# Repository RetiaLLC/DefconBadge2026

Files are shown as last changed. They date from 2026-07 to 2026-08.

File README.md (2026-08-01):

# DEF CON Badge (2026) — ESP32-S3

Everything you need to hack on the Retia DEF CON badge: hardware docs, pinouts, flashable firmware (including **DOOM**, a full **NES emulator**, **Meshtastic**, **MeshCore**, and **Reticulum**), and example code to get you from "just unboxed" to writing your own firmware.

> **🚀 Start here: the [Badge Launcher v2 "Touch"](https://github.com/RetiaLLC/badge-launcher/releases/tag/v2.0.0)** — the flagship badge experience. One flash + one micro-SD card turns the badge into a pick-what-you-run device: two full-color **touch mesh messengers** (MeshCore + Meshtastic MUI), classic Meshtastic, a **Reticulum RNode**, an **NES emulator** with a 37-game homebrew library, and **WLEDkitty** — switchable from an on-badge menu in ~10 seconds, no computer needed. Comes with a `MESH-101.md` that gets two badges messaging over LoRa in minutes. Flash it from your browser at [scriptkitty.sh](https://scriptkitty.sh). *(Requires a FAT micro-SD card — true of launcher v1 too. Prefer DOOM resident in flash? [Launcher v1 "Classic"](https://github.com/RetiaLLC/badge-launcher/releases/tag/v1.0.0).)*

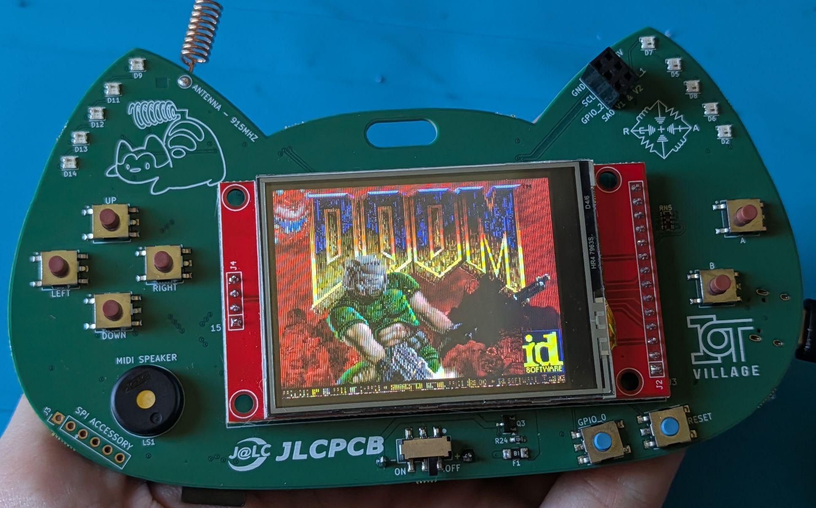
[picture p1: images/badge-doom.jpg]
The badge running DOOM


*Yes, that's DOOM. Flash it in one command — see below.*

## What's on the badge

| | |
|---|---|
| MCU | ESP32-S3-WROOM-1 — dual-core 240 MHz, WiFi + BLE, **8 MB flash**, **2 MB PSRAM**, native USB-C |
| Display | 2.4″ ILI9341 240×320 color TFT + XPT2046 resistive **touch** (MSP2402 module) |
| Radio | RFM95W **LoRa** 915 MHz (SX1276), U.FL antenna |
| Input | 6 face buttons (d-pad + A/B) + BOOT button usable as a 7th |
| Storage | micro-SD slot (tested to 16 GB SDHC) |
| Blinkies | 10× WS2812B NeoPixels, green debug LED |
| Sound | Piezo buzzer (MOSFET-driven) |
| Expansion | SAO v2, QWIIC (I²C), UART header, SPI header, off-board NeoPixel connector |
| Power | 2×AA (boost) or USB-C, auto-switching |

## Quick start: flash DOOM

```bash
pip install esptool
esptool --chip esp32s3 --port <PORT> write-flash 0x0 firmware/doom/doom-audio.factory.bin
```

`<PORT>` is `/dev/cu.usbmodem*` (macOS), `/dev/ttyACM0` (Linux), or `COMx` (Windows). Full instructions, port-finding, and un-bricking: [docs/flashing.md](docs/flashing.md).

## Repo map

```
docs/            pinout.md ← START HERE · hardware.md · flashing.md · sd-card.md
firmware/
  doom/          DOOM shareware, audio + silent builds (flash & play)
  meshtastic/    Meshtastic 2.7.23, standard + low-power builds
  reticulum/     RNode v1.85 — the badge as a Reticulum LoRa transceiver
examples/
  hello-badge/   buttons + LED + buzzer in 100 lines (your first build)
  sd-test/       mount/format/read/write the micro-SD slot
hardware/        KiCad 8 sources + schematic PDF
```

## The three things that bite everyone

1. **The touch controller and the display-module SD slot have crossed data lines** — hardware SPI can't reach them. The main SD slot and everything else work normally. Details: [docs/pinout.md](docs/pinout.md#hardware-quirks).
2. **Native-USB download-mode trap** — DTR-toggling serial monitors + reset = badge stuck "waiting for download". Fix: any esptool command ending in hard-reset. Details: [docs/flashing.md](docs/flashing.md#recovery).
3. **Never TX on LoRa without an antenna.** Receiving is safe; transmitting into nothing can cook the PA.

## Firmware in this repo

- **[DOOM](firmware/doom/)** — the 1993 classic, natively, full speed. D-pad moves, A fires, GPIO0 switches weapons. Audio build plays SFX through the piezo.
- **[Meshtastic](firmware/meshtastic/)** — off-grid LoRa mesh messaging with phone app support; standard, power-optimized, and full **color touch UI (MUI)** builds. **Ready-to-flash touch UI: [meshtastic-mui-v2.7.23 release](https://github.com/RetiaLLC/DefconBadge2026/releases/tag/meshtastic-mui-v2.7.23)** — on-screen keyboard, node map, touch region picker, phone TCP API alongside the home screen.
- **[MeshCore](firmware/meshcore/)** — the badge as a [MeshCore](https://meshcore.io) LoRa mesh node, hardware-verified badge-to-badge (messages + ACKs). The flagship build is a full **standalone touchscreen mesh communicator** — chats, contacts, channels, on-screen keyboard, RF monitor + spectrum analyzer, chimes, D-pad nav — that is simultaneously a BLE companion for the official MeshCore phone app. Plain companion (BLE/USB) builds too. **Ready-to-flash images: [meshcore-v1.0.0 release](https://github.com/RetiaLLC/DefconBadge2026/releases/tag/meshcore-v1.0.0).** Source: **[RetiaLLC/MeshCore](https://github.com/RetiaLLC/MeshCore)** (board variant) + **[RetiaLLC/wadamesh](https://github.com/RetiaLLC/wadamesh)** (touch messenger), both branch `retia-badge`.
- **[Reticulum / RNode](firmware/reticulum/)** — turns the badge into an [RNode](https://unsigned.io/rnode/): a host-controlled 915 MHz LoRa transceiver for the [Reticulum network stack](https://reticulum.network) (NomadNet, Sideband, MeshChat). The default build shows the live RNode status screen (frequency, airtime, channel load, signal) on the TFT. Flash, provision with `rnodeconf`, done — hardware-verified against a Nibble Zero RNode. Full toolkit, source, and Nibble Zero builds live in **[RetiaLLC/NibbleReticulum](https://github.com/RetiaLLC/NibbleReticulum)**.
- **[ESP32 Bus Pirate](firmware/buspirate/)** — a multi-protocol hardware-hacking multitool on the badge TFT (also USB-serial / Wi-Fi web CLI): I²C/SPI/UART/1-Wire/JTAG bus tools with **on-screen bus scan + live register monitor** and a **BME280 dashboard** that colours the ears by temperature, plus a full **on-screen LoRa/RF suite** — heat-map **waterfall**, packet **sniffer**, live **RSSI meter**, band **scanner**, and a **Meshtastic monitor** that decodes real mesh packets on-screen (with a **MeshCore** sniffer preset). Wi-Fi/BLE scanners too. **Start with the [beginner's guide](firmware/buspirate/GUIDE.md).** ⚠ Transmit- & attack-capable (Wi-Fi deauth, BLE spoof, RF jam) — **authorized use only**. Ready-to-flash: **[RetiaLLC/ESP32-Bus-Pirate @ badge-v1.2.1](https://github.com/RetiaLLC/ESP32-Bus-Pirate/releases/tag/badge-v1.2.1)**, ported from [KonradIT/geo-tp](https://github.com/KonradIT/ESP32-Bus-Pirate).
- **[Anemoia NES](https://github.com/RetiaLLC/Anemoia-DefconBadge)** *(standalone repo)* — a full NES emulator: put `.nes` ROMs on the micro-SD card, browse and launch them on the badge, and play with the D-pad + A/B. Save states, chiptune audio through the piezo, and a one-button START/SELECT scheme (tap BOOT = START, hold = pause menu). Ready-to-flash image on the [release page](https://github.com/RetiaLLC/Anemoia-DefconBadge/releases/latest) (also attached to this repo's `anemoia-v1.0.0` release), plus a [curated list of legally-free homebrew games](https://github.com/RetiaLLC/Anemoia-DefconBadge/blob/main/GAMES.md) tested on the badge. Ported from [Shim06/Anemoia-ESP32](https://github.com/Shim06/Anemoia-ESP32).

## Building your own firmware

Both examples are PlatformIO ESP-IDF projects with the badge board definition included — copy one as a template. The short version:

```bash
pip install platformio
cd examples/hello-badge
pio run -t upload --upload-port <PORT>
```

Then open a serial monitor at 115200 and press buttons.

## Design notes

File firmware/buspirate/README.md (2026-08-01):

# ESP32 Bus Pirate

A port of the open-source **[ESP32 Bus Pirate](https://github.com/KonradIT/ESP32-Bus-Pirate)** (geo-tp / KonradIT) to the badge — a multi-protocol hardware-hacking multitool driven from the badge TFT, USB-serial CLI, or a Wi-Fi web CLI.

Source & release: **[RetiaLLC/ESP32-Bus-Pirate @ badge-v1.2.1](https://github.com/RetiaLLC/ESP32-Bus-Pirate/releases/tag/badge-v1.2.1)** (branch `retia-badge-port`, all badge support gated behind `-DDEVICE_RETIA_BADGE`).

**New to it? Read the [beginner's guide](GUIDE.md)** — walks through every on-screen demo you can run on a bench.

## ⚠ Read before flashing — transmit- & attack-capable
Alongside the benign bus tools this firmware can **transmit and attack**: Wi-Fi (scan/sniff/**deauth**/nmap), Bluetooth LE (scan/**spoof**/sniff), LoRa/Sub-GHz **transmit**, and bus/RF **jam**. It ships as a full-capability image — not a passive build.

**Use only on hardware, networks, and RF you own or are authorized to test.** Transmitting against systems you don't own may be illegal. You are responsible for lawful use.

## What works on the badge (verified on hardware)
- **ILI9341 TFT UI** + **d-pad/A·B** nav; auto-boots to the USB-serial CLI.
- **LoRa on-screen suite** (on-board RFM95W / SX1276, new SX127x driver):
  - **`waterfall`** — heat-map spectrum analyzer (blue→red), peak-hold.
  - **`receive`** — packet sniffer: a rolling on-screen list (#, RSSI, length, ASCII).
  - **`rssi`** — big live signal meter + held-peak marker.
  - **`scan`** — peak-hold heat spectrum across a band.
  - **`mesh` → Receive** — Meshtastic monitor, decoded packets on-screen; verified vs a **real Meshtastic node**. `send` for TX.
  - **`meshcore`** — tunes to MeshCore's 915/SF10 PHY and sniffs (payloads AES-128, shown raw).
  - Core `send`/`receive`/`sniff`/`setfreq` **TX + RX verified badge-to-badge**.
- **I²C** — bus scan + live register **monitor on the TFT**; **`bme`** decodes a **BME280** (temp/humidity/pressure) on screen and colours the ear NeoPixels by temperature.
- **LED** — 10 ear NeoPixels (fill / rainbow / chase / wave).
- **Wi-Fi** and **BLE** scanners; **UART** sniff/autobaud.

## Wiring targets
I²C on the **SAO header (J5)**: 3V3 / GND / SDA=GPIO35 / SCL=GPIO36. UART on J4 (TX 43 / RX 44). ⚠ The badge's Qwiic connectors are pin-reversed vs. the standard — use **J5**, not Qwiic.

## Flash it
Browser (recommended, with the authorization prompt): **[catbadge.online](https://catbadge.online)** or **[scriptkitty.sh](https://scriptkitty.sh)**. Or with esptool:
```bash
esptool --chip esp32s3 --before default-reset --after hard-reset \
  write-flash --flash-mode dio --flash-freq 40m --flash-size 8MB 0x0 buspirate-badge.factory.bin
```

`buspirate-badge.factory.bin` — SHA-256 `695a924b2502d7e25b8057c3875d239c373009075f11e1cfee5f0772d6851cc6`

## Wi-Fi web CLI terminal
Boot into **WiFi Hotspot** or **WiFi Connect** and the badge serves an interactive web
terminal — type commands from any browser (phone included), no cable needed. The earlier
"Connection lost" flakiness is **fixed**: the badge now binds its reply socket from the
incoming WebSocket frame (the handshake binding didn't stick on this ESP-IDF), sends
complete (non-fragmented) frames, and reserves enough HTTP handlers for every route.
USB serial and browser Web Serial ([catbadge.online](https://catbadge.online)) remain
available for cabled use.

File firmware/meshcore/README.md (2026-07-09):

# MeshCore on the badge

Off-grid LoRa mesh messaging — [MeshCore](https://meshcore.io) v1.16.0 ported to the badge (SX1276 DIO0-only radio, ILI9341 + XPT2046 touch, all on the shared SPI bus). US 915 MHz preset by default; hardware-verified badge-to-badge with delivery ACKs.

**Flashable images live on the [`meshcore-v1.0.0` release](https://github.com/RetiaLLC/DefconBadge2026/releases/tag/meshcore-v1.0.0):**

| Image | What it is |
|---|---|
| `meshcore-touch-messenger.factory.bin` | **The one to use** — full standalone touchscreen mesh communicator (chats, contacts, channels, on-screen keyboard, RF monitor/spectrum apps, chimes, D-pad nav) that is *also* a BLE companion for the phone app |
| `meshcore-companion-ble.factory.bin` | Badge as a radio for the MeshCore phone app; pairing PIN shows on the badge screen |
| `meshcore-companion-usb.factory.bin` | Companion over USB serial for `meshcore-cli` / meshcore.js / the web client |

```bash
esptool --chip esp32s3 --port <PORT> write-flash 0x0 meshcore-touch-messenger.factory.bin
```

Source: [RetiaLLC/MeshCore](https://github.com/RetiaLLC/MeshCore/tree/retia-badge) (board variant) · [RetiaLLC/wadamesh](https://github.com/RetiaLLC/wadamesh/tree/retia-badge) (touch messenger). Repeater and room-server roles build from the same variant (`Retia_DCBadge_repeater` / `_room_server`).

**Badge-launcher note:** these are factory images with their own partition tables — they are **not** launcher SD-card guests. The touch messenger's app image (2.7 MB) exceeds the launcher's 2.375 MB shared slot, and MeshCore stores its identity/contacts in the same flash regions Meshtastic uses for settings, so running it as a guest would clobber them. Flash over USB instead (10 seconds), and hold UP at reset any time to get back to the launcher's factory image if you have it installed.

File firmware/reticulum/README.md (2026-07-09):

# Reticulum (RNode)

The badge as an [RNode](https://unsigned.io/rnode/): a host-controlled
[Reticulum](https://reticulum.network) LoRa transceiver. Plug it into a
computer or phone and use it with `rnsd`, NomadNet, MeshChat, or Sideband —
the badge handles the 915 MHz radio, the host runs the network stack.

Canonical repo (source, flash/provision scripts, Nibble Zero builds):
**[RetiaLLC/NibbleReticulum](https://github.com/RetiaLLC/NibbleReticulum)**

> ⚠️ **Attach a 915 MHz antenna (U.FL) before transmitting.** Transmitting
> without an antenna can damage the radio's PA. Receiving is safe.

## Flash it

```bash
pip install esptool rns
esptool --chip esp32s3 --port <PORT> write-flash 0x0 rnode-1.85-tft.factory.bin
```

Then provision the EEPROM (one time — makes it a valid homebrew RNode):

```bash
rnodeconf <PORT> -r --platform 80 --product f0 --model fe --hwrev 1
rnodeconf --info <PORT>   # should report: RNode v1.85, Normal (host-controlled)
```

Or let the automated script in NibbleReticulum do both:
`./DefconBadge/flash_dcbadge.sh <PORT>`.

| File | What |
|---|---|
| `rnode-1.85-tft.factory.bin` | **Recommended.** RNode v1.85 with the status screen on the badge's ILI9341 (mode, frequency, airtime, channel load, signal quality — 2.5x scale, full panel height). Flash at `0x0`. |
| `rnode-1.85.factory.bin` | Same firmware, headless (display dark). Flash at `0x0`. |

## Use it with Reticulum

Add to your `~/.reticulum/config` (LA-area community channel shown —
see the [NibbleReticulum SIGINT survey](https://github.com/RetiaLLC/NibbleReticulum/blob/main/SIGINT.md)):

```ini
[[RNode Badge]]
  type = RNodeInterface
  enabled = yes
  port = /dev/ttyACM0
  frequency = 914875000
  bandwidth = 125000
  spreadingfactor = 8
  codingrate = 5
  txpower = 17
```

Verified on hardware: bidirectional badge ↔ Nibble Zero Reticulum link,
3/3 packets delivered with proofs (914.875 MHz / SF8 / 125 kHz / CR5).

## Notes for builders

- Source: [`RetiaLLC/RNode_Firmware` branch `retia-stable`](https://github.com/RetiaLLC/RNode_Firmware/tree/retia-stable),
  targets `make firmware-retia_dcbadge_tft` (display) / `make firmware-retia_dcbadge` (headless, board ID `0x47`)
- `MODEM SX1276` only — the RFM95W's DIO1/BUSY are not routed
- The badge's SPI pins are **not** the ESP32-S3 defaults; the driver needs the
  explicit `SPI.begin(13, 12, 11, 48)` (already handled on the branch)
- Touch and SD chip-selects (14/39) are parked high at boot; the radio driver
  must never call `SPI.end()` on this board (shared display bus)
- Status: green debug LED (GPIO 2) blinks RX/TX; first NeoPixel = status color

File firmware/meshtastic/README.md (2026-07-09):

# Meshtastic

The badge is a fully working [Meshtastic](https://meshtastic.org) node: 915 MHz LoRa mesh, TFT UI, buttons, BLE to the phone app. Firmware 2.7.23 with a badge-specific variant (`hwModel PRIVATE_HW`).

> ⚠️ **Attach a 915 MHz antenna (U.FL) before joining a mesh.** Transmitting without an antenna can damage the radio's PA. And set your region before use:
> ```bash
> pip install meshtastic
> meshtastic --port <PORT> --set lora.region US
> ```

## Flash it

```bash
esptool --chip esp32s3 --port <PORT> write-flash 0x0 meshtastic-2.7.23-standard.factory.bin
```

| File | What |
|---|---|
| `meshtastic-2.7.23-standard.factory.bin` | Stock-behavior build for the badge variant (classic button-driven TFT UI). |
| `meshtastic-2.7.23-lowpower.factory.bin` | Power-tuned build: idle draw cut ~39% (NeoPixels off by default, BLE off until enabled by phone), B button = Back/Cancel, 40 ms debounce, battery light-sleep available as opt-in (`--set power.is_power_saving true` — battery-only deployments; USB presence inhibits sleep). |
| `meshtastic-2.7.23-mui-touch.factory.bin` | **Experimental color touch UI** (Meshtastic device-ui / LVGL, `touchscreen-build-bleoff`). Full touchscreen operation out of the box — on-screen keyboard, tap navigation — despite the badge's crossed touch data lines (worked around with a calibrated bit-banged XPT2046 driver). D-pad + A/B also work as a keypad. Bluetooth is off in this build (it conflicts with the touch UI's home screen); phone/client connectivity is WiFi/TCP (port 4403). Showcase build; the low-power build is the daily driver. |

A Meshtastic badge enumerates over USB with its MAC in the port name (e.g. `usbmodem744DBD216494`) — that's normal.

## Variant files

`variant.h` / `pins_arduino.h` in this directory are the badge variant used to build these images (RFM95W on the shared SPI bus, ILI9341 TFT, buttons as trackball input, NeoPixel ambient lighting). Drop them into `variants/esp32s3/` in the Meshtastic firmware tree to build your own.

Notes for builders:
- `USE_RF95` only — the radio's DIO1/BUSY are not routed, SX126x variants won't work
- USB serial console carries the protobuf client API, **not** a text log (human-readable log is on UART J4)
- The badge has no battery-voltage sense; don't enable battery-percentage features

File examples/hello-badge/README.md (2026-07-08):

# hello-badge

Your first badge program: heartbeat on the green LED, a beep and a console line for every button press (each button gets its own pitch — B is the loudest, it sits on the piezo's 4 kHz resonance).

```bash
pio run -t upload --upload-port <PORT>
pio device monitor -p <PORT> -b 115200
```

Press buttons. That's it. Copy this project as the starting point for your own firmware — the board definition in `boards/` already knows the badge's flash/PSRAM setup.

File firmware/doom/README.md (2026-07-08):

# DOOM

Yes, really. PrBoom 2.5.0 running the shareware **DOOM** (Knee-Deep in the Dead) natively on the badge — 320×240 fullscreen, all game logic, attract demos, saves-free arcade style. The WAD is memory-mapped straight out of flash so the whole game fits in the S3's 2 MB PSRAM.

## Flash it

```bash
esptool --chip esp32s3 --port <PORT> write-flash 0x0 doom-audio.factory.bin
```

| File | Sound |
|---|---|
| `doom-audio.factory.bin` | Sound effects through the piezo buzzer (loud-ish, crunchy, gloriously PC-speaker). Three self-test chirps at boot. |
| `doom-silent.factory.bin` | Mute. Same game otherwise. |

Music is not implemented in either build (there's no MIDI synth in this port — yet).

## Controls

| Input | Action |
|---|---|
| D-pad | Move forward/back, turn left/right |
| **A** (SW8) | Fire — also Enter in menus |
| **B** (SW7) | Use / open doors — Space in menus |
| **A+B together** | Escape (open/close menu) |
| **BOOT** (SW2, top of badge) | Switch weapon (best-available toggle) |

At the title screen: **A+B** → menu → **A** to start New Game.

## How it works / source

Port derived from [cocus/esp32-ili9341-doom-lvgl](https://github.com/cocus/esp32-ili9341-doom-lvgl) (itself from [espressif/esp32-doom](https://github.com/espressif/esp32-doom)), retargeted to the badge:

- Badge pin map, all six face buttons + BOOT wired to Doom keys
- IWAD (`doom1.wad`, shareware — freely redistributable) and PrBoom's data WAD live in dedicated flash partitions, memory-mapped, lumps read in place
- Zone allocator backed by PSRAM with cache eviction — fits the 2 MB
- 8-bit palette renderer → RGB565 over 40 MHz SPI
- Audio build: 1-bit sigma-delta on the buzzer GPIO, 22 kHz sample timer, heavy gain+clip (a piezo demands it)

Flash layout inside the factory image: bootloader `0x0`, partition table `0x8000`, app `0x10000`, `doom1.wad` `0x210000`, `prboom-plus.wad` `0x630000`.

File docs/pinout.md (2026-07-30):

# GPIO Pinout — 2024 DEF CON Badge (ESP32-S3)

MCU: **ESP32-S3-WROOM-1** module — dual-core LX7 @ 240 MHz, **8 MB flash** (GigaDevice, QIO-capable), **2 MB embedded PSRAM** (quad, 80 MHz), native USB.

> ⚠️ Read the [quirks](#hardware-quirks) section before writing firmware. Several pins are shared, one pair is crossed in hardware, and the native-USB download mode has a trap.

## Complete GPIO map

| GPIO | Function | Direction | Notes |
|-----:|---|---|---|
| 0 | **BOOT button (SW2**, silkscreen "GPIO_0"**)** + off-board NeoPixel connector J8 (level-shifted to 5 V) | in / out | Strap pin: hold low through a reset → ROM download mode. Free as a button input after boot. |
| 1 | SAO connector GPIO1 (J5 pin 5) | any | |
| 2 | **Green debug LED** (330 Ω) + SAO GPIO2 (J5 pin 6) | out | |
| 3 | **LEFT button (SW3)** | in | Active-low, external 10 kΩ pull-up. Debounce caps C7–C12 are DNP (not populated). |
| 4 | **UP button (SW4)** | in | Active-low, 10 kΩ pull-up |
| 5 | **DOWN button (SW5)** | in | Active-low, 10 kΩ pull-up |
| 6 | **RIGHT button (SW6)** | in | Active-low, 10 kΩ pull-up |
| 7 | **B button (SW7)** | in | Active-low, 10 kΩ pull-up |
| 8 | **A button (SW8)** | in | Active-low, 10 kΩ pull-up |
| 9 | **Buzzer** (silkscreen "MIDI SPEAKER"; 330 Ω → NMOS gate → PS1240P02CT3 piezo from +5 V, 1 kΩ parallel) | out | Square wave ≈4 kHz is loudest (piezo resonance). 1-bit sigma-delta works for sampled audio (quiet, crunchy). |
| 10 | **micro-SD card CS** (dedicated slot, 10 kΩ pull-up) | out | Shares the SPI bus. Verified working — see [sd-card.md](sd-card.md). |
| 11 | **SPI MOSI** (shared bus) | out | Also: touch T_DO and module-SD "SD_MISO" land here — see quirks. |
| 12 | **SPI MISO** (shared bus) | in | Also: touch T_DIN and module-SD "SD_MOSI" land here — see quirks. |
| 13 | **SPI SCK** (shared bus) | out | Display runs at 40 MHz; SD at 20 MHz; touch ≤2.5 MHz. |
| 14 | **Touch controller CS** (XPT2046 on display module) | out | |
| 15 | 32.768 kHz crystal (XTAL_32K_P) | — | Not available as GPIO |
| 16 | 32.768 kHz crystal (XTAL_32K_N) | — | Not available as GPIO |
| 17 | **On-board NeoPixels** — 10× WS2812B-2020, right ear (5) then left ear (5) | out | |
| 18 | Broken out to MCU_gpio bus, unused on the board | any | |
| 19 | USB D− | — | |
| 20 | USB D+ | — | |
| 21 | **LoRa DIO0 / IRQ** (RFM95W) | in | |
| 35 | **I²C SDA** — SAO (J5) and QWIIC (J6) | any | Chosen for software compatibility with HakCat Nuggets (no dedicated I²C pins). |
| 36 | **I²C SCL** — SAO (J5) and QWIIC (J6) | any | |
| 37 | **Accessory SPI CS** (J3, unpopulated header) | out | |
| 38 | **LoRa RESET** (RFM95W, 10 kΩ pull-up) | out | |
| 39 | **Display-module SD slot CS** | out | ⚠️ That slot's data lines are crossed — see quirks. |
| 40 | **TFT DC** (data/command) | out | |
| 41 | **TFT RESET** | out | |
| 42 | **Touch IRQ** (XPT2046 PENIRQ, active low) | in | |
| 43 | **UART TX** (J4 accessory header, 330 Ω series) | out | Default ESP-IDF console is here unless retargeted to USB. |
| 44 | **UART RX** (J4) | in | |
| 45 | Unconnected | — | Strap pin (VDD_SPI voltage) — leave alone |
| 46 | Unconnected | — | Strap pin — leave alone |
| 47 | **TFT CS** (ILI9341) | out | |
| 48 | **LoRa CS** (RFM95W, 10 kΩ pull-up) | out | |

## The shared SPI bus

One SPI bus (SCK 13 / MOSI 11 / MISO 12) serves **five** peripherals, each with its own chip-select:

| Device | CS | Max clock |
|---|---|---|
| ILI9341 TFT (240×320) | 47 | 40 MHz (overclocked, works) |
| RFM95W LoRa | 48 | 10 MHz |
| micro-SD slot (dedicated) | 10 | 20 MHz |
| SD slot on display module | 39 | — (crossed lines, unusable as-is) |
| XPT2046 touch | 14 | 2.5 MHz (crossed lines — bit-bang only) |
| Accessory header J3 | 37 | — |

**Rule: before using any bus device, drive every other CS high.** A floating CS (especially the LoRa radio's) will corrupt bus traffic.

## Hardware quirks

1. **Touch data lines are crossed.** The XPT2046's T_DIN (its input) is wired to GPIO12 — the bus **MISO** net — and T_DO (its output) to GPIO11, the bus **MOSI** net. Hardware SPI can therefore never talk to the touch controller. It *is* reachable by bit-banging with reversed pin roles (drive commands on 12, read data on 11) while holding the bus. T_IRQ (GPIO42, active low on touch) works normally.
2. **The display module's own SD slot has the same crossing** ("SD_MISO"→GPIO11/MOSI, "SD_MOSI"→GPIO12/MISO). Use the **dedicated** micro-SD slot (CS 10) instead — it's wired correctly and verified working.
3. **Native-USB download-mode trap.** The USB-Serial/JTAG peripheral wires host DTR to GPIO0. A serial monitor that asserts DTR, combined with a reset, drops the badge into ROM download mode ("waiting for download") instead of booting. Flash with esptool `--after hard-reset`, avoid DTR-toggling monitors, and see [flashing.md](flashing.md#recovery) for recovery.
4. **Display backlight is hardwired to 3.3 V** — always on, not software-controllable (~0.2–0.35 W). A white screen just means the panel is in sleep with the backlight lit.
5. **No battery voltage sense.** GPIO45/46 are unconnected; +BATT and +USB_IN are power-only. Firmware cannot read battery level — USB presence is the only "external power" signal (USB plugged in ⇒ battery path disabled).
6. **LoRa DIO1/BUSY are not routed.** Use SX127x/RF95 drivers only (`USE_RF95`, `LORA_DIO1 = NC`); SX126x variants will not work.
7. **8 MB flash despite what USB says.** Chip identification may report "FH4R2 (4 MB)" but the module carries an 8 MB GigaDevice part (`flash-id`: c8:4017). Partition freely up to 8 MB.
8. **Merged-image builders: use DIO flash mode.** A factory image with a QIO bootloader header boot-loops at ROM stage (`TG0WDT` reset + `ets_loader.c 78`). The second-stage bootloader enables QIO itself; the header must stay DIO.
9. **⚠️ Qwiic/STEMMA-QT connectors (J4, J6) are pin-reversed vs. the standard — do NOT plug in stock Qwiic sensors.** The JST-SH footprint is mounted so the physical pin order is **backwards** relative to the SparkFun-Qwiic / Adafruit-STEMMA-QT cable standard, so a standard cable lands **power and ground swapped/scrambled** — the sensor never powers up and a small host (e.g. a Nugget) can brown out and fail to boot. Affects both I²C (J6) and the UART-on-Qwiic (J4), and the same footprint is shared across other Retia boards. **Workaround:** wire I²C to the **SAO header (J5)** instead — pin 1 = +3.3 V, 2 = GND, 3 = SDA/GPIO35, 4 = SCL/GPIO36 — after metering. Full analysis + fix in [hardware-errata.md](hardware-errata.md).

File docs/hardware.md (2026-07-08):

# Hardware Guide — 2024 DEF CON Badge

A sheet-by-sheet walkthrough of the design ([schematic.pdf](../hardware/schematic.pdf), KiCad 8 sources in [hardware/kicad](../hardware/kicad/)).

## System overview

```
2×AA ──SW9──F1──► TPS61023 boost (5.1V) ─┐
                                          ├─► +5V rail ──► TLV62569 buck ──► +3.3V rail
USB-C VBUS ──────────► diode D10 ────────┘
```

- **ESP32-S3-WROOM-1** module (8 MB flash, 2 MB PSRAM)
- **MSP2402** 2.4″ display module: ILI9341 240×320 TFT + XPT2046 resistive touch + micro-SD slot
- **RFM95W** 915 MHz LoRa radio (SX1276) with U.FL antenna connector
- 10× **WS2812B-2020** NeoPixels (two "ears" of 5)
- Piezo buzzer, 6 face buttons + BOOT/RESET, dedicated micro-SD slot
- SAO v2, QWIIC, UART, SPI accessory headers, off-board NeoPixel connector

## Power (sheet 7)

Two power sources, diode-OR'd onto the +5 V rail:

- **Battery path:** 2×AA → power switch SW9 → polyfuse F1 → **TPS61023** boost converter set to **5.1 V** (R27 750k / R28 100k). The extra 0.1 V biases D10's drop so USB wins when both are present.
- **USB path:** VBUS → diode D10 → +5 V rail. A MOSFET (Q4) **disables the boost converter whenever USB is present** — so battery current is zero on USB power, and firmware can treat "USB plugged in" as "not on battery".
- **3.3 V:** TLV62569 buck (R30 453k / R31 100k → 3.318 V) feeds the MCU, radio, display logic.
- Reverse-battery indicator: red/green LED pair across the input.

Consequences for firmware: no brownout mystery — a badge that resets under load on AA power is hitting the boost converter's current limit (NeoPixels + radio TX + display are a real load). The display backlight is a constant ~0.2–0.35 W drain you cannot switch off.

## MCU block (sheet 2)

- SW1 = RESET (EN), SW2 = BOOT (GPIO0) — the standard ESP32 programming pair.
- Green debug LED on GPIO2 (also on the SAO header).
- 32.768 kHz crystal on GPIO15/16 for RTC deep-sleep timing.
- Full pin map: see [pinout.md](pinout.md).

## Display + touch + module SD (sheet 4)

The MSP2402 module carries three devices; the badge fans all of them onto the shared SPI bus through DR-series resistor networks:

- **TFT (ILI9341):** CS 47, DC 40, RST 41 — wired correctly, runs happily at 40 MHz. Backlight pin is tied to 3.3 V (always on).
- **Touch (XPT2046):** CS 14, IRQ 42, clock shared — but **T_DIN/T_DO are swapped** relative to the bus (T_DO→MOSI net, T_DIN→MISO net). Hardware SPI cannot reach it; reversed-role bit-banging can. IRQ works and is the cheap "is anyone touching" signal.
- **Module SD slot:** CS 39 — **same MISO/MOSI swap**, so leave it alone and use the dedicated slot below.

## Dedicated micro-SD (sheet 5)

Correctly wired SPI slot: CS **10** (10 kΩ pull-up), plus the shared bus pins. Verified working at 20 MHz with a 16 GB SDHC card — see [sd-card.md](sd-card.md) and [examples/sd-test](../examples/sd-test/).

## Buttons (sheet 8)

Six face buttons — LEFT 3, UP 4, DOWN 5, RIGHT 6, B 7, A 8 — all to ground with 10 kΩ pull-ups. Footprints for RC debounce caps (C7–C12) exist but are **not populated**; debounce in software (~40 ms works well).

## Buzzer (sheet 3)

GPIO9 → 330 Ω → NMOS gate (10 kΩ pull-down) → **PS1240P02CT3 piezo** from +5 V with 1 kΩ parallel damping resistor. It's a resonant tweeter, loudest around 4 kHz:

- Simple beeps: LEDC PWM square wave, 2–5 kHz. Loud and clean.
- Sampled audio: 1-bit sigma-delta (or LEDC-PWM DAC) works, but off-resonance output is quiet and gritty. Apply heavy gain + clipping. (The Doom build does exactly this.)

## LoRa radio (sheet 9)

**RFM95W-915S2** (SX1276): CS 48, RESET 38, DIO0/IRQ 21, shared SPI. DIO1+ are **not connected** — SX127x-style drivers only. Antenna via U.FL (J1) or the TP1 wire pad.

> ⚠️ **Never transmit without a 915 MHz antenna attached** — you can damage the PA. Receiving is safe.

## NeoPixels (sheets 10, 6)

- On-board: GPIO17 → 10× WS2812B-2020, right ear first (D2,D6,D8,D5,D7), then left (D9,D11,D12,D13,D14). Powered from 3.3 V (works fine for WS2812B at 3.3 V logic).
- Off-board connector J8: **GPIO0** through a proper MOSFET level shifter (Q2) to 5 V logic, with 5 V supply on the header. Note the GPIO0 double-duty: driving external pixels means the pin also feels button SW2 and the boot strap — keep it high-Z at reset.

## Connectors (sheet 6)

| Ref | What | Pins |
|---|---|---|
| J3 | SPI accessory (unpopulated) | MISO 12, MOSI 11, SCK 13, CS 37, 3.3 V, GND |
| J4 | UART | TX 43, RX 44 (330 Ω series), 3.3 V, GND |
| J5 | **SAO v2** | SDA 35, SCL 36, GPIO1, GPIO2, 3.3 V, GND |
| J6 | **QWIIC** | SDA 35, SCL 36, 3.3 V, GND |
| J7 | USB-C | D− 19, D+ 20, CC pulldowns populated |
| J8 | NeoPixel out | GPIO0 (5 V level-shifted), 5 V, GND |
| J9 | 2×AA battery | via SW9 + polyfuse |

I²C on GPIO35/36 was picked deliberately for software compatibility with existing HakCat Nugget projects.

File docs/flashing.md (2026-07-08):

# Flashing Guide

Everything here uses the badge's **USB-C port** — no programmer needed. The ESP32-S3's native USB shows up as a serial port when you plug it in.

## 1. Install esptool

```bash
pip install esptool
```

## 2. Find the port

| OS | Port looks like |
|---|---|
| macOS | `/dev/cu.usbmodem*` |
| Linux | `/dev/ttyACM0` |
| Windows | `COM5` (check Device Manager) |

> A badge running Meshtastic enumerates with its MAC address in the port name (e.g. `usbmodem744DBD216494`); a badge in the ROM bootloader or running most other firmware shows a generic name.

## 3. Flash a factory image

Every `.factory.bin` in this repo is a **complete merged image** (bootloader + partition table + app + data). One command, always at offset 0:

```bash
esptool --chip esp32s3 --port /dev/cu.usbmodem1101 write-flash 0x0 doom-audio.factory.bin
```

The badge resets and boots the new firmware when the write finishes. If esptool can't connect, see manual download mode below.

## Manual download mode

Hold **BOOT (SW2)**, tap **RESET (SW1)**, release BOOT. The badge is now in the ROM serial bootloader waiting for esptool.

## Recovery

### Badge is stuck "waiting for download" after flashing

The S3's native USB wires the host's **DTR line toward GPIO0**, so serial monitors that assert DTR can hold the badge in download mode across resets. Fixes:

- Run any esptool command ending in a reset, e.g. `esptool --chip esp32s3 --port PORT flash-id` — it exits via "Hard resetting via RTS pin..." which boots the app.
- Close any open serial monitor before flashing or resetting (one client per port!).
- When scripting your own serial reader: hold DTR **steadily** asserted and never toggle it; toggling is what re-traps the chip.

### Badge boot-loops with `rst:0x7 (TG0WDT_SYS_RST)` and `ets_loader.c 78`

The flash image's bootloader header says QIO, which the ROM loader can't use on this flash chip (the second-stage bootloader is what switches to QIO). Reflash a known-good image, or if you're building merged images yourself: **`esptool merge-bin --flash-mode dio`**, never `qio`.

### Nuclear option

```bash
esptool --chip esp32s3 --port PORT erase-flash   # ~8 s, wipes everything incl. saved settings
```
Then flash a factory image.

## Reading the serial console

Firmware in this repo routes its console to the USB port. Any terminal at 115200 baud works, **but** prefer one that doesn't toggle DTR on open (see trap above). `pio device monitor` and most IDE monitors are fine while the app is running — just close them before flashing.

## Building from source

The examples are PlatformIO projects:

```bash
pip install platformio
cd examples/sd-test
pio run                                    # build
pio run -t upload --upload-port PORT       # flash
```

The board definition ([examples/sd-test/boards/defcon-badge.json](../examples/sd-test/boards/defcon-badge.json)) encodes the badge: ESP32-S3, 8 MB flash (QIO), 2 MB quad PSRAM.

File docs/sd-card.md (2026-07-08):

# Using the micro-SD Card

The badge has **two** SD interfaces. Only one of them works — know which.

## The two slots

| Slot | CS | Status |
|---|---|---|
| **Dedicated micro-SD slot** on the badge PCB | GPIO **10** | ✅ Works — use this one |
| Slot on the back of the display module | GPIO 39 | ❌ Data lines crossed in routing (MISO/MOSI swapped) — unusable with hardware SPI |

Both share the badge SPI bus (SCK 13 / MOSI 11 / MISO 12) with the display, touch, LoRa radio and accessory port. **Park every other chip-select high** (GPIOs 47, 48, 39, 37, 14) before touching the card, or bus traffic will collide.

## Verified configuration

Tested on real hardware with a 16 GB SDHC card ("SS16G"):

```
Name: SS16G
Type: SDHC
Speed: 20.00 MHz (limit: 20.00 MHz)
Size: 15193MB
sd-test: Wrote /sd/badge_test.txt
sd-test: Read back: Hello from the 2024 DEF CON badge!
sd-test: SD TEST: PASS (15193MB card, wrote and read /sd/badge_test.txt)
```

- Bus: SDSPI on `SPI2_HOST`, CS 10, 20 MHz (the ESP-IDF SDSPI default)
- Filesystem: FAT (FAT32 for cards ≥ ~2 GB). A FAT-formatted card mounts as-is.
- Cards that arrive exFAT (common ≥64 GB) or unformatted need a FAT format first — the example does it on the badge via `format_if_mount_failed = true` (**erases the card**), or format it FAT32 on your computer.

## Try it

[examples/sd-test](../examples/sd-test/) is a complete PlatformIO project that mounts the card (formatting if needed), prints the card info, writes `/sd/badge_test.txt`, reads it back, and blinks the green LED slow for PASS / fast for FAIL. Console output on USB at 115200.

```bash
cd examples/sd-test
pio run -t upload --upload-port <PORT>
```

## Minimal code

```c
spi_bus_config_t bus = { .mosi_io_num = 11, .miso_io_num = 12,
                         .sclk_io_num = 13, .quadwp_io_num = -1, .quadhd_io_num = -1 };
spi_bus_initialize(SPI2_HOST, &bus, SDSPI_DEFAULT_DMA);

sdmmc_host_t host = SDSPI_HOST_DEFAULT();
host.slot = SPI2_HOST;
sdspi_device_config_t slot = SDSPI_DEVICE_CONFIG_DEFAULT();
slot.gpio_cs = 10;
slot.host_id = SPI2_HOST;

esp_vfs_fat_sdmmc_mount_config_t cfg = { .format_if_mount_failed = true,
                                         .max_files = 5, .allocation_unit_size = 16*1024 };
sdmmc_card_t *card;
esp_vfs_fat_sdspi_mount("/sd", &host, &slot, &cfg, &card);
// ... standard stdio on /sd/... from here
```

Sharing the bus with a live display (as Doom does) additionally requires serializing access — take a lock around SD transactions so they interleave between display DMA frames.

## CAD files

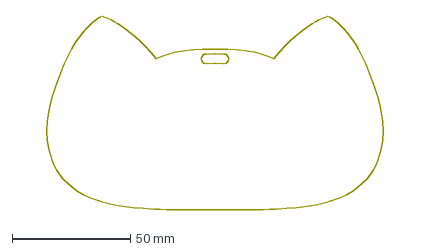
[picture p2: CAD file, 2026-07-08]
hardware/kicad/outlines/smoothbadge.dxf
168.2 x 82.8 mm

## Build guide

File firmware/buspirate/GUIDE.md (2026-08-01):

# ESP32 Bus Pirate on the DEF CON Badge — Beginner's Guide

> Turn your badge into a **multi-protocol hardware & radio analysis multitool** with
> a live color display. This guide gets you from "just flashed" to running eye-catching,
> hands-on demos — **no laptop screen required, the badge shows you everything.**
>
> Every command and on-screen result below was tested on the actual badge on a bench.

## Jump to

- [Quick start](#quick-start) — flash, connect, the CLI basics
- [LoRa demos](#lora-demos-the-stars) ⭐ — waterfall, sniffer, RSSI meter, scanner, Meshtastic/MeshCore
- [I²C sensor dashboard](#i2c-sensor-dashboard) — scan + decode a sensor on screen
- [GPIO pin tools](#gpio-pin-tools) — "is this pin alive?" + on-screen logic/analog scope
- [Wi-Fi](#wi-fi) — scan, MAC lookup, and driving the badge wirelessly
- [Bluetooth LE](#bluetooth-le) — scan the air
- [UART](#uart) — sniff a live serial line
- [LED ears](#led-ears) — because it's a badge
- [Needs an add-on module](#needs-an-add-on-module) — what's *not* on the badge
- [Command reference](#command-reference)

> ⚠️ **Radio safety & authorization.** This build can transmit (LoRa/Wi-Fi/BLE) and
> includes attack-capable commands (deauth, spoof, jam, spam). **Only test hardware,
> networks and RF you own or have written permission to test.** This guide sticks to
> **passive, receive-only demos** — the safe, always-legal stuff. Never transmit on
> LoRa without a 915 MHz antenna attached, or you can damage the radio.

---

## Quick start

1. **Flash** the badge — browser flasher at [catbadge.online](https://catbadge.online), or `esptool … write-flash 0x0 buspirate-badge.factory.bin`.
2. **Tap RESET.** It boots straight to the USB-serial CLI at **115200 baud**.
3. Useful anywhere:
   - `help` — commands for the current mode · `man` — built-in topic guide (examples, syntax, safety)
   - `mode` — list protocols · `mode <name>` — enter one (prompt changes: `I2C>`, `LORA>`, …)
   - `system` — opens a status shell (summary, memory, network, partitions, reboot…); pick `1` for the summary
   - `mode hiz` — safe idle · **ENTER** — stop a running command

> 💡 **Entering a mode asks a few setup questions** (pins, speed, radio settings), each
> showing its default in brackets like `SDA GPIO [35]:` — **just press ENTER to accept
> every default.** All examples below assume you took the defaults.

You can also drive the whole CLI **from a browser** (no terminal app) or **over Wi-Fi** —
see [Drive it wirelessly](#wi-fi).

### Where things are

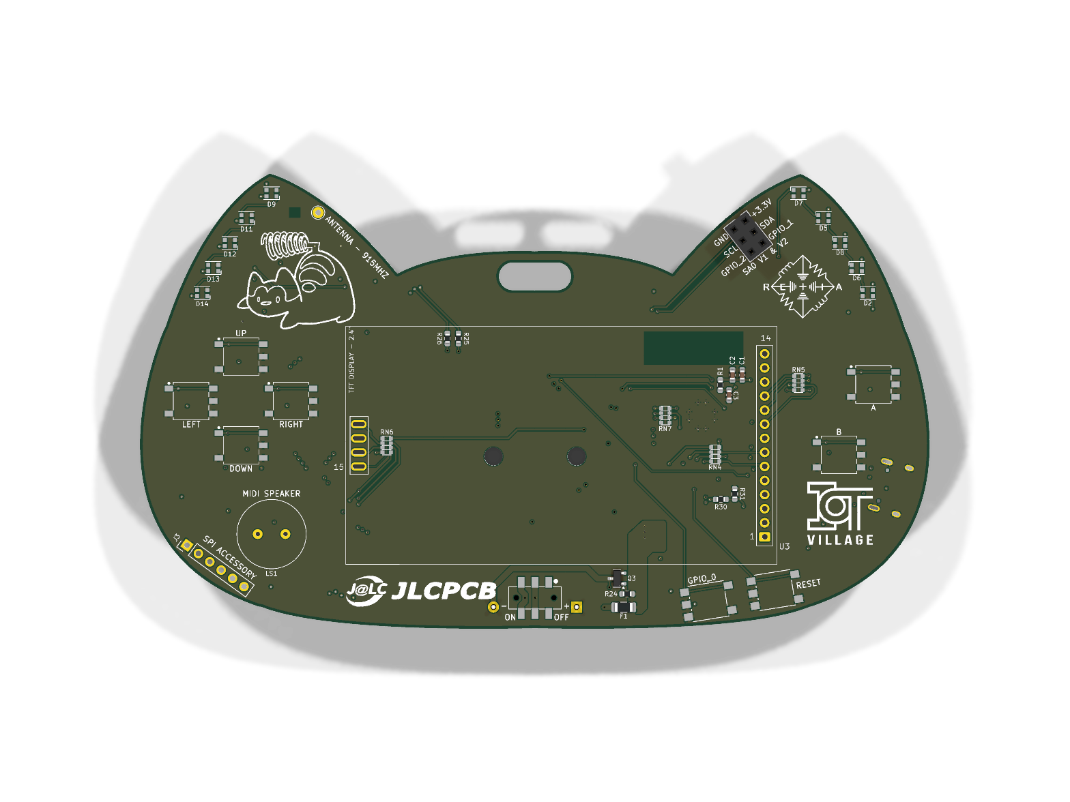
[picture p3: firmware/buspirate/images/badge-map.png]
Badge map — SAO port, d-pad + A/B/RESET buttons, 915 MHz antenna, SPI accessory header


The bits this guide uses: the **SAO port** (top-right, labelled `+3.3V / SDA / SCL /
GPIO_1 / GPIO_2 / GND`) for I²C add-ons; the **d-pad + A** for the boot menu; **A / B /
RESET** buttons; the **915 MHz antenna** pad for LoRa; and the **SPI accessory** header.
The **Qwiic (J6)** I²C connector is on the back.

---

## LoRa demos (the stars) ⭐

LoRa is where the on-screen demos shine.
```
mode lora
```
It reports the on-board radio (`RFM95W / SX127x`) and asks *"Configure radio settings?"* —
answer **N** for the sensible defaults. You're at `LORA>`.

> Attach the **915 MHz antenna** before anything that transmits (`send`, `spam`). The
> receive/scan demos are safe without one, but signals will be weak.

| Command | What the screen does |
|---|---|
| `waterfall` | **Heat-map spectrum analyzer** — blue/green where quiet, **yellow/red where something transmits**; peak frequency in the header. Try Start `902` End `928` Step `0.1`. |
| `rssi` | **Big live signal meter** + colored bar + held-peak marker. Move a transmitter closer, the bar climbs and turns red. |
| `scan` | **Peak-hold heat spectrum** across a range — every channel that's been active lights up and stays lit. |
| `receive` | **Packet sniffer** — a rolling on-screen list of frames: number, **RSSI**, length, ASCII preview. Have another badge `send hello world`. |
| `send <text>` | Transmit a frame (needs the antenna). Two badges: one `receive`, the other `send`. |

**Meshtastic monitor** — the badge decodes *real* Meshtastic:
```
mesh
```
From the numbered menu: **2** → preset `LongFast`, **3** → frequency `906.875`, **4** →
channel key `AQ==`, **7** → **Receive packets**. The screen becomes a **Mesh Monitor**
showing decoded packets — `!nodeid` + text/type — for any Meshtastic traffic on the
default channel. (Verified decoding live packets from a stock Meshtastic node.) Menu
**6** sends a text a real Meshtastic node/phone will receive.

**MeshCore sniffer** — one command:
```
meshcore
```
Tunes the radio to MeshCore's default US PHY (`915 MHz / SF10`) and drops into the
on-screen sniffer. MeshCore frames appear as RSSI + raw bytes (group payloads are
AES-128 encrypted, so they show raw, not decoded). It's a *separate* mode from
Meshtastic — different frequency/spreading-factor, can't monitor both at once.

---

## I²C sensor dashboard

The best hands-on demo if you have a sensor. Wire it to the badge's **Qwiic connector
`J6`** (the white JST) — match the sensor's **3V3 · GND · SDA · SCL** to the badge:

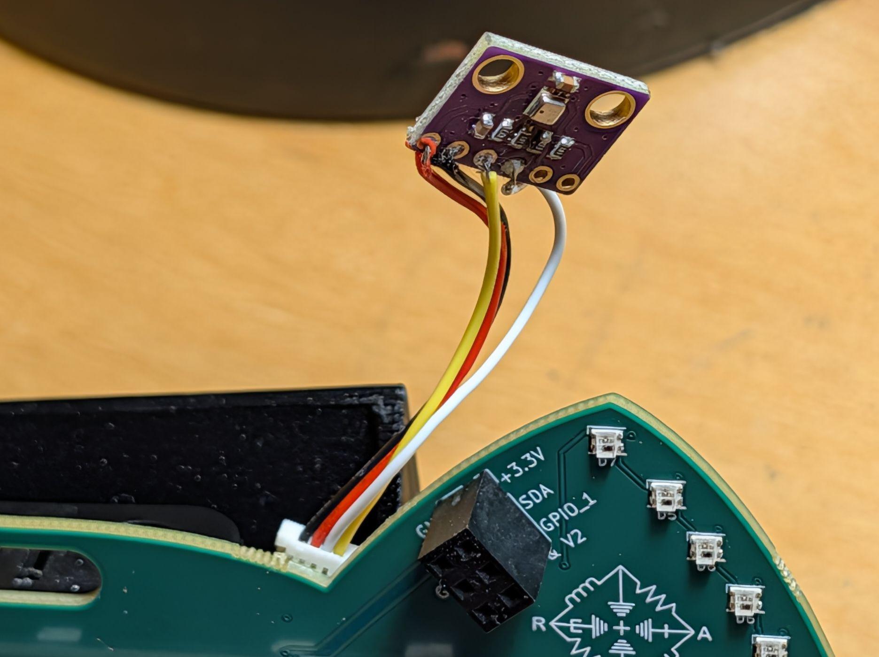
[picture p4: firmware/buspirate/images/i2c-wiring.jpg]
Wiring a BME280 I²C sensor into the badge's J6 Qwiic connector


> ⚠️ **`J6` (Qwiic) is pin-reversed vs a standard Qwiic/STEMMA cable** (see
> [`docs/hardware-errata.md`](../../docs/hardware-errata.md)) — a plug-and-play cable
> lands power/ground scrambled. **Hand-wire the four lines to match** the badge's
> silkscreen (`+3.3V / SDA / SCL / GND`), exactly like the photo above. Either I²C
> connector works — **`J5` (the SAO port)** carries the same bus (see below).

The badge's whole I²C bus is **SDA = GPIO35, SCL = GPIO36** — those are the default
`mode i2c` pins, and they're wired to *both* `J6` (Qwiic) and `J5` (the SAO port).

```
mode i2c
```
Answer `SDA GPIO [35]:`, `SCL GPIO [36]:`, `Frequency [100000]:` — **ENTER three times**.
Then:
```
scan
```
The screen shows a **device list**; serial prints `Found device at 0x76`. A BME280/BMP280
environment sensor answers at `0x76` (or `0x77`).
```
bme 0x76
```
Decodes the sensor **onto the badge**: a two-column **BME280** dashboard with **T / H / P**
(e.g. `T 24.9 C · H 49 %RH · P 1001 hPa`) plus raw registers — and **the ear LEDs change
color with the temperature.** Warm the sensor with your fingers and watch both move.
`monitor <addr>` mirrors live register reads to the screen. ENTER stops.

---

## Talk to an SAO on the SAO port

The **SAO port (`J5`)** — the standard 1×6 add-on header — is wired straight to the same
I²C bus (**SDA GPIO35 · SCL GPIO36**) plus two GPIOs (**GPIO1, GPIO2**, on pins 5 & 6).
So you can interrogate anything plugged into it with **no extra wiring**:

- **I²C parts on the SAO** (sensors, EEPROMs, LED drivers): `mode i2c` → `scan` finds the
  address, then `read` / `dump` / `bme` / `monitor` — same as the sensor dashboard above.
- **The SAO's two GPIO lines** (GPIO1, GPIO2): scope them on the badge screen with
  `logic 1` / `logic 2` (digital waveform) or `analogic 1` (live voltage), or poke them in
  `mode dio` (`read 1`, `measure 1`).

Great for reverse-engineering a mystery SAO: **scan its I²C address, then scope its GPIO
pins** — all from the badge, no laptop.

---

## GPIO pin tools

"Is this pin alive?" — and two commands that draw a **scope trace on the badge screen**.
These work from any prompt (they're global).

> **Use a broken-out GPIO**, not a reserved one. Safe to probe on this badge:
> **1, 2, 18, 35, 36, 37** (SAO/accessory header) and **43, 44** (UART header). The
> d-pad, flash and PSRAM pins are protected and will say *"GPIO is protected."*

```
logic 35
```
**On-screen logic analyzer** — samples a digital pin and draws its **waveform on the TFT**
(title `Logic Analyzer · GPIO 35`). Point it at a clock, a data line, any toggling pin; a
floating pin just reads flat.

```
analogic 1
```
**On-screen analog scope** — plots a pin's changing **voltage** as a live green trace (ADC
pins are GPIO 1–10). Good for a potentiometer, an analog sensor output, a drifting rail.

For quick checks, `mode dio` gives a pin toolkit:
```
mode dio
read 35        # instantaneous logic level  ->  GPIO 35 = 0 (LOW)
measure 35     # counts edges for 1 s and reports the frequency
sniff 35       # stream edge changes
```
Great for figuring out whether a pin is a clock, a data line, or dead.

---

## Wi-Fi

```
mode wifi
scan
```
Lists nearby **access points** — SSID, security, BSSID, channel, signal. Fully passive.
Handy follow-ups:
```
sniff                       # passive beacon/probe capture, cycling channels
connect <SSID> <password>   # join a network (needed for the online tools below)
lookup AA:BB:CC:DD:EE:FF    # MAC -> vendor  (requires connect first)
```

**Drive the badge from a browser or over Wi-Fi:**

- **Easiest — browser Web Serial.** Plug in over USB and use the terminal at
  [catbadge.online](https://catbadge.online) — no app, no Wi-Fi. Works in **Firefox**,
  Chrome, or Edge (Firefox added Web Serial support, so it's no longer Chromium-only).
- **Over Wi-Fi (no cable) — the web CLI is a *boot mode*, not a serial command.**
  **Reset the badge** — a terminal-type menu appears for ~6 s: **d-pad LEFT/RIGHT** to
  highlight **WiFi Hotspot**, then press **A** to select (no input defaults to USB). The
  badge makes its own Wi-Fi network **`ESP32-Bit-Pirate`** (password `readytoboard`) and
  serves the CLI web page at **192.168.4.1**.
  > The interactive terminal works from any browser, phones included — type a command and
  > the output streams back live. (The earlier "Connection lost" flakiness is fixed.) Web
  > Serial over USB (above) is still there if you'd rather stay on a cable.

> The plain `ap <ssid> <password>` serial command just makes a bare access point (no CLI) —
> it's for bridging, not the web UI. To serve the web CLI you must **boot** into a Wi-Fi mode.

> The `deauth`, `spam`, `spoof`, `flood` commands here are transmit/attack — **authorized
> use only**, not part of this guide.

---

## Bluetooth LE

```
mode bluetooth
scan
```
Lists nearby **BLE advertisers** — MAC, RSSI, name/flags. Expect a sea of phones and
earbuds broadcasting proximity beacons (Apple Continuity, Google Nearby), all with
**randomized MACs** — a nice live lesson in BLE privacy.

---

## UART

UART shines pointed at a **real serial source** — e.g. the bench's own UART console.
Wire the badge's UART **RX (GPIO44)** to the source's **TX**, and **GND to GND**.
```
mode uart
autobaud        # auto-detects the line's baud rate (listens on RX GPIO 44)
snifftxt        # streams decoded text as it flows by  (sniffraw = raw hex)
```
That turns the badge into a passive serial tap — great for reading what a device chatters.

---

## LED ears

```
mode led
```
Answer the setup — LED count **10**, and a **low brightness like 40** (the ears are bright;
high brightness on USB-only power can brown out the board). Then:
```
rainbow          # moving rainbow
fill 00FF00      # solid green   (fill 000000 = off)
set 3 FF0000     # light a single ear by index
```

---

## Needs an add-on module

Many Bus Pirate modes need an **external chip/module the badge doesn't carry**. They work
if you wire the module to the SAO/accessory header, but they're **not** plug-and-play demos:

- **SPI** (`mode spi`) — needs an SPI flash/EEPROM to `sniff`/dump.
- **1-Wire** (`mode 1wire`) — needs a DS18B20, iButton, etc.
- **Sub-GHz** (CC1101), **RF24** (nRF24L01), **CAN** (MCP2515), **RFID/NFC** (PN532),
  **FM** (Si4713), **Cellular** (GSM/LTE modem), **Ethernet** (W5500), **Infrared**
  (IR LED/receiver), **Smart-card**, **Microwire/3-wire**, **I²S** audio — each needs its
  named module.
- **JTAG/SWD** scanning — needs a target MCU on the jumpers.

**On-board and ready right now:** LoRa, I²C, UART, 1-Wire, GPIO/DIO, LED (ears), Wi-Fi,
BLE, USB-HID, SD card, and the on-screen `logic`/`analogic` scope.

---

## Command reference

| Mode | Enter | Star demo | Also |
|---|---|---|---|
| **LoRa** | `mode lora` | `waterfall`, `rssi`, `scan`, `receive`, `mesh`→7 | `send`, `meshcore`, `status` |
| **I²C** | `mode i2c` | `scan`, `bme 0x76` | `monitor`, `ping`, `read` |
| **GPIO** | *(global)* / `mode dio` | `logic <pin>`, `analogic <pin>` | `measure`, `read`, `sniff` |
| **Wi-Fi** | `mode wifi` | `scan` | `lookup`, `sniff`, `ap` (web CLI) |
| **BLE** | `mode bluetooth` | `scan` | `sniff`, `status` |
| **UART** | `mode uart` | `autobaud` → `snifftxt` | `sniffraw`, `bridge` |
| **LED** | `mode led` | `rainbow` | `fill RRGGBB`, `set <i> RRGGBB` |

**Anywhere:** `help` · `man` (topic guide) · `mode` (list) · `system` (status shell) · `mode hiz` (idle) · **ENTER** (stop).

---

*Ported from [KonradIT/ESP32-Bus-Pirate](https://github.com/KonradIT/ESP32-Bus-Pirate)
(recipes: [geo-tp.github.io/ESP32-Bit-Pirate](https://geo-tp.github.io/ESP32-Bit-Pirate/recipes/)).
On-screen LoRa/I²C demos and the Meshtastic/MeshCore tooling are Retia badge additions.
Transmit- & attack-capable — authorized use only.*

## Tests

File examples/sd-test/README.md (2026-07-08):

# sd-test

Smoke test for the badge's micro-SD slot (the dedicated one, CS GPIO10 — not the crossed-wire slot on the display module; see [docs/sd-card.md](../../docs/sd-card.md)).

Mounts the card FAT (**formatting it if it doesn't mount** — erases the card!), prints card info, writes `/sd/badge_test.txt`, reads it back.

```bash
pio run -t upload --upload-port <PORT>
pio device monitor -p <PORT> -b 115200
```

- Green LED blinking **slow** = PASS
- Green LED blinking **fast** = FAIL (is a card inserted? FAT-formattable?)

Verified on hardware with a 16 GB SDHC card at 20 MHz.

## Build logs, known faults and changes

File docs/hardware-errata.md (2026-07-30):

# Hardware Errata — 2024 DEF CON Badge

Known hardware bugs on the shipped/sample boards, with evidence and workarounds.

---

## ERRATA-01 — Qwiic / STEMMA-QT connectors are pin-reversed (power/ground swapped)

**Severity:** High — can damage attached sensors and prevent a host from booting.
**Affected refs:** **J6** (I²C Qwiic), **J4** (UART on a Qwiic-shaped connector).
**Also affects:** other Retia boards that use the same `retia_component_library` Qwiic
footprint (e.g. the Bluetooth Nugget) — the bug reproduces there identically.

### Symptom

Plug any standard SparkFun-Qwiic / Adafruit-STEMMA-QT sensor into J6 with a standard
QT cable and:

- the sensor's **power LED never lights** (it isn't getting valid 3.3 V),
- an I²C scan finds **nothing**,
- on a smaller host (Nugget) the board **won't even boot** with the sensor attached
  (the mis-connected sensor loads/browns out the 3.3 V rail),
- reproduced across **3 different Adafruit Qwiic sensors** → not a dead sensor.

### Root cause

The connector's **physical pin order is backwards relative to the Qwiic/STEMMA-QT
standard**, so a standard cable delivers **power and ground on the wrong pins**
(reversed/scrambled). Evidence from `hardware/kicad/`:

- Footprint: `retia_component_library:QWIIC_CONNECTOR_GENERIC_1x04-1MP_P1.00mm_Horizontal`
  — a **generic** `kicad-footprint-generator` JST-SH (SM04B-SRSS-TB) part, **not**
  SparkFun's official Qwiic footprint.
- Both J6 and J4 are placed on the **back copper (`layer "B.Cu"`)** of the board.
- The nets on the pads are individually correct — J6: pad1 GND, pad2 +3.3 V, pad3
  SDA/GPIO35, pad4 SCL/GPIO36 — **but** the combination of the generic footprint's
  pin-1 orientation and the back-layer (mirrored) placement means the pad that the
  cable's **GND** wire seats into is not the GND pad, and likewise for +3.3 V. The
  standard cable therefore reverse-/cross-powers the sensor.

The Qwiic/STEMMA-QT standard is a 4-pin JST-SH 1.0 mm connector, pin order
**GND · 3.3 V · SDA · SCL** (black/red/blue/yellow). The badge connector does not
present that order at the physical cable interface.

> Note: **J4 is a Qwiic-*shaped* UART port** (pads 3/4 are UART TX GPIO43 / RX GPIO44,
> silk "UART Connector"), physically identical to the I²C Qwiic J6 (silk "QWIIC
> CONNECTOR"). Even once the polarity is fixed, do not confuse the two.

### Confirm on a unit (30 s, no risk)

Power the board, **nothing plugged in**, meter the 4 contacts of J6: find which pin
reads **+3.3 V** and which reads **0 V/GND**. Compare to the QT cable (black = GND,
red = 3.3 V). If the badge's 3.3 V pin lines up with the cable's **black** wire (or
GND with red), the connector is reversed → do not plug stock sensors in as-is.

### Workaround (use today)

Wire I²C to the **SAO header J5** (0.1″ 2×3, unambiguous, meterable) — same I²C bus:

| J5 pin | Net | QT/sensor wire |
|---|---|---|
| 1 | +3.3 V | red / VIN / 3Vo |
| 2 | GND | black |
| 3 | SDA (GPIO35) | blue |
| 4 | SCL (GPIO36) | yellow |
| 5 / 6 | GPIO1 / GPIO2 | — |

**Meter J5 pins 1 & 2 for 3.3 V / GND before connecting.** Verified working: a
BME280 hand-wired to J5 enumerated at 0x76 and returned live data (chip-ID reg
0xD0 = 0x60; compensated temperature ≈ 26 °C).

Alternatively, a **polarity-reversed / hand-rewired QT cable** makes J6 usable, but
per-cable rework is error-prone — SAO is safer.

### Fix (next board rev)

In `retia_component_library`, correct the Qwiic connector so a standard STEMMA-QT/Qwiic
cable seats **GND→GND, 3.3 V→3.3 V**. Options:
- Replace the generic `kicad-footprint-generator` SM04B footprint with SparkFun's
  official Qwiic footprint (correct pin-1 keying), **or**
- Keep the part but fix the pad-to-pin-1 assignment / connector orientation so the
  physical cable interface matches the standard, **and** re-verify after the front/back
  layer mirror.
- Re-check every board that instantiates this shared footprint (badge J4/J6, Nugget,
  any others).

Verify the fix by metering the assembled connector against a known-good Qwiic host
before shipping.

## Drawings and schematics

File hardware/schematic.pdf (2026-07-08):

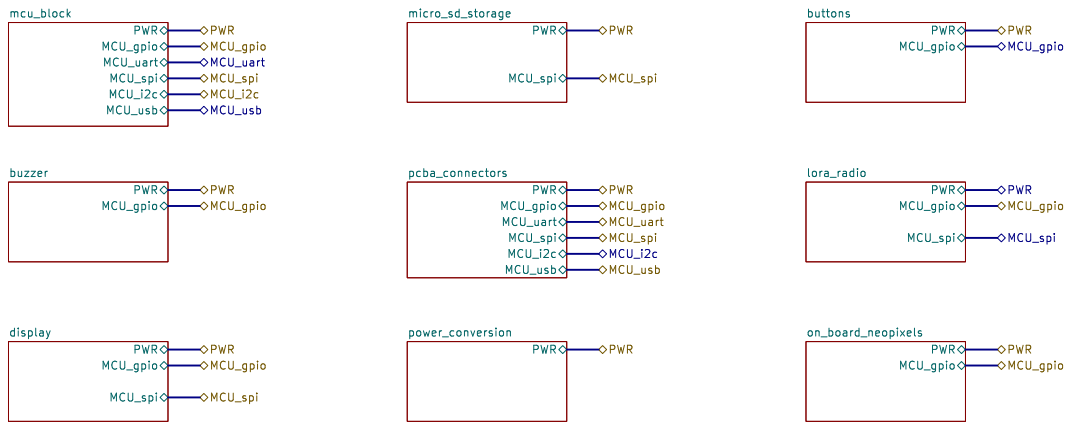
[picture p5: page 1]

Id: 1/10 Title: File: 2024_def_con_badge_v1.kicad_sch Sheet: /

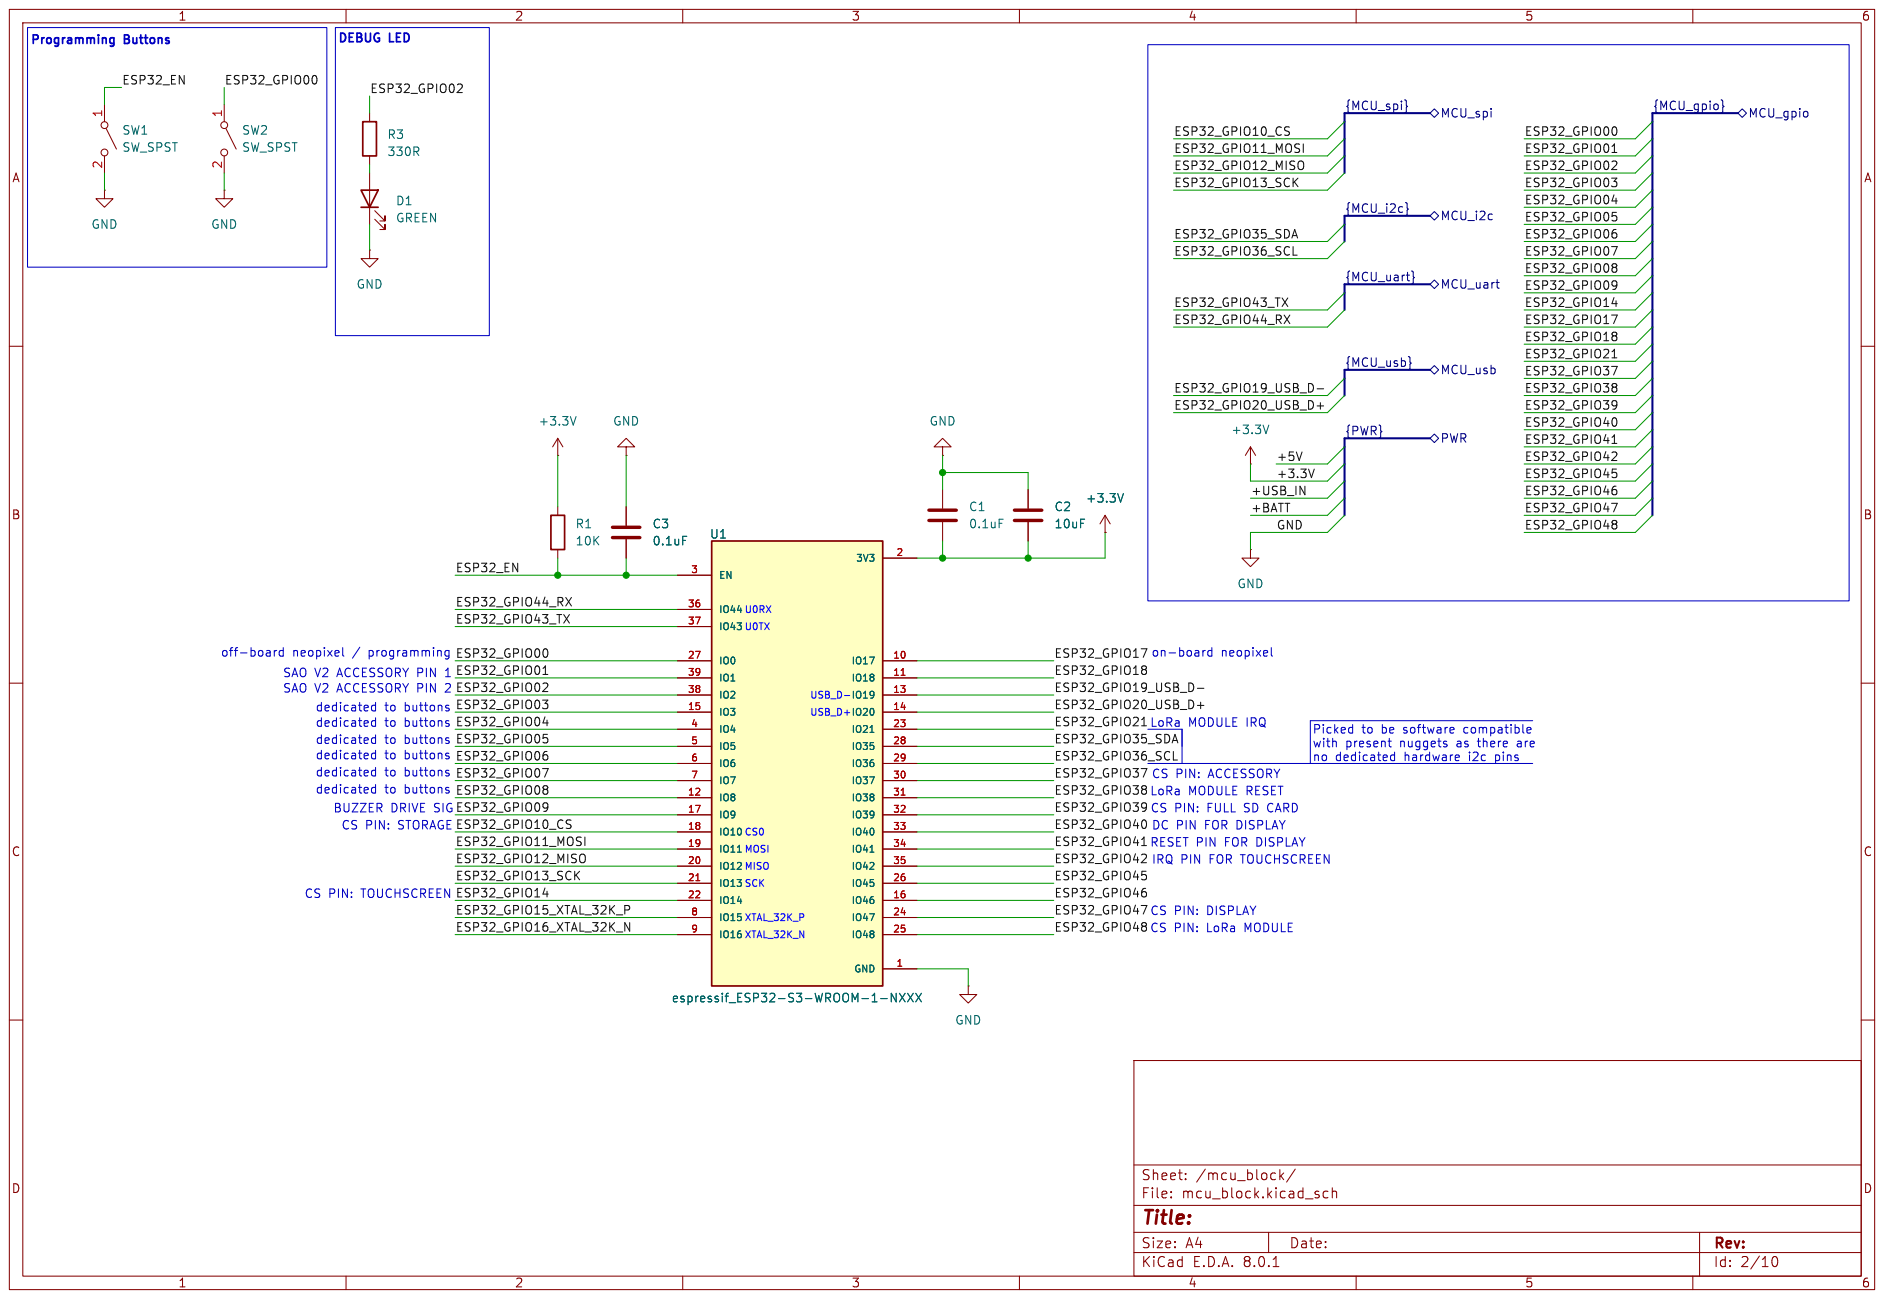
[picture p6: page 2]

LoRa MODULE RESET RESET PIN FOR DISPLAY DC PIN FOR DISPLAY CS PIN: DISPLAY

IRQ PIN FOR TOUCHSCREEN

CS PIN: LoRa MODULE

Id: 2/10 Title: File: mcu_block.kicad_sch Sheet: /mcu_block/ GND

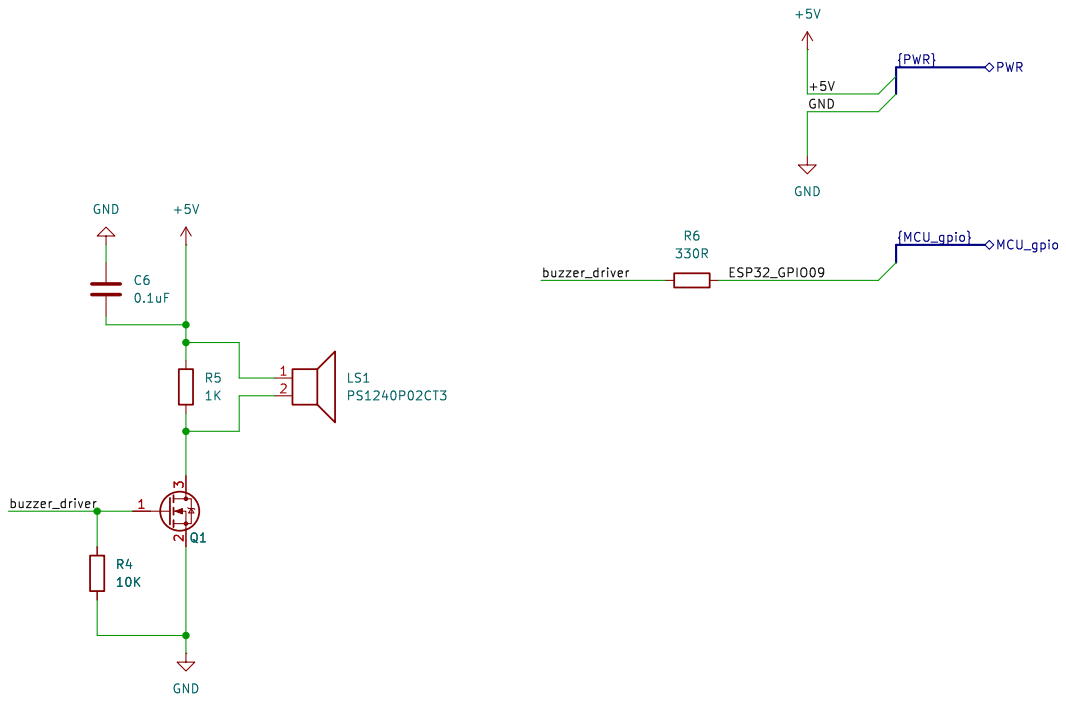
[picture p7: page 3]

Id: 3/10 Title: File: buzzer.kicad_sch Sheet: /buzzer/ GND

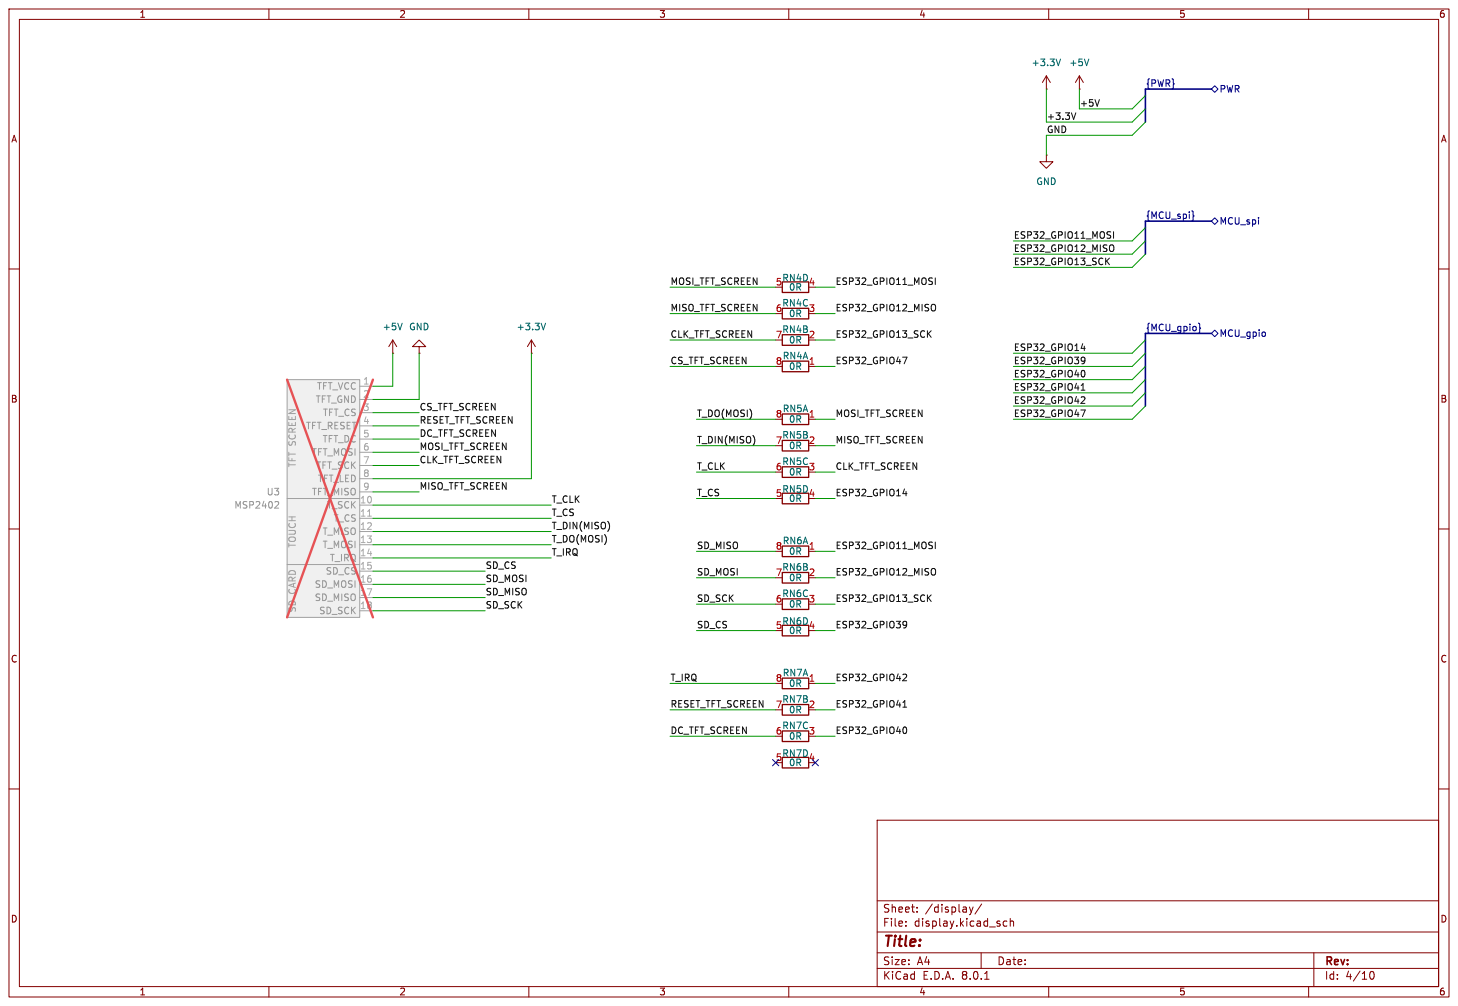
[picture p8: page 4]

0R SD CARD TFT SCREEN TOUCH

Id: 4/10 Title: File: display.kicad_sch Sheet: /display/

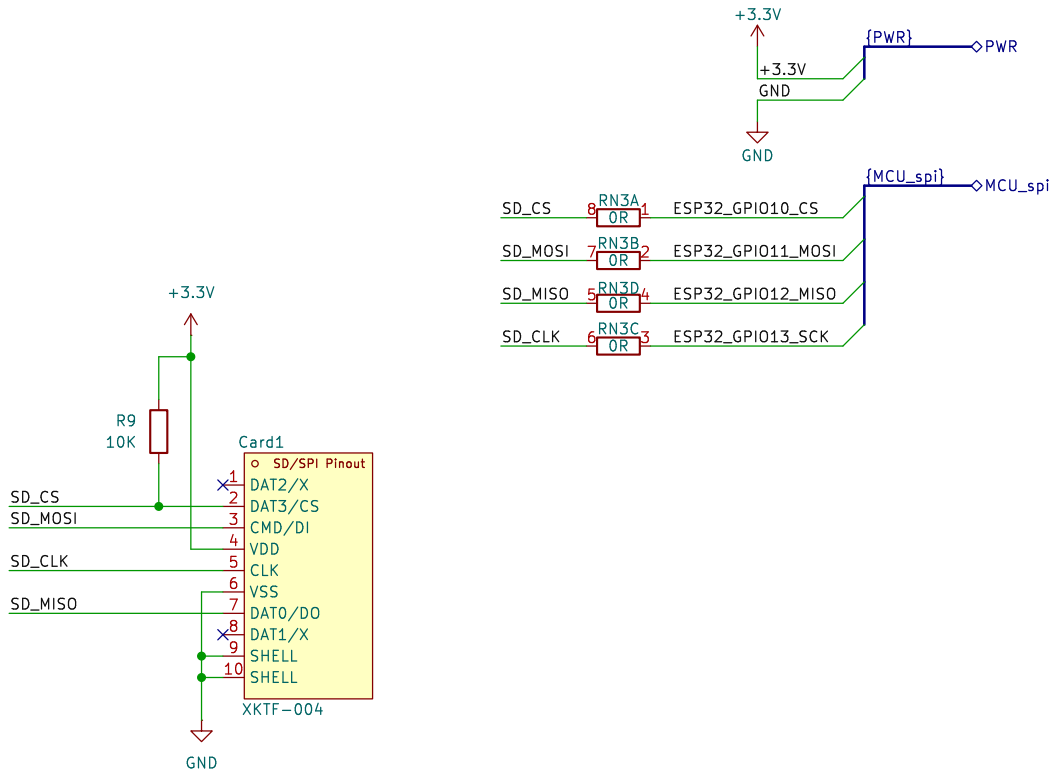
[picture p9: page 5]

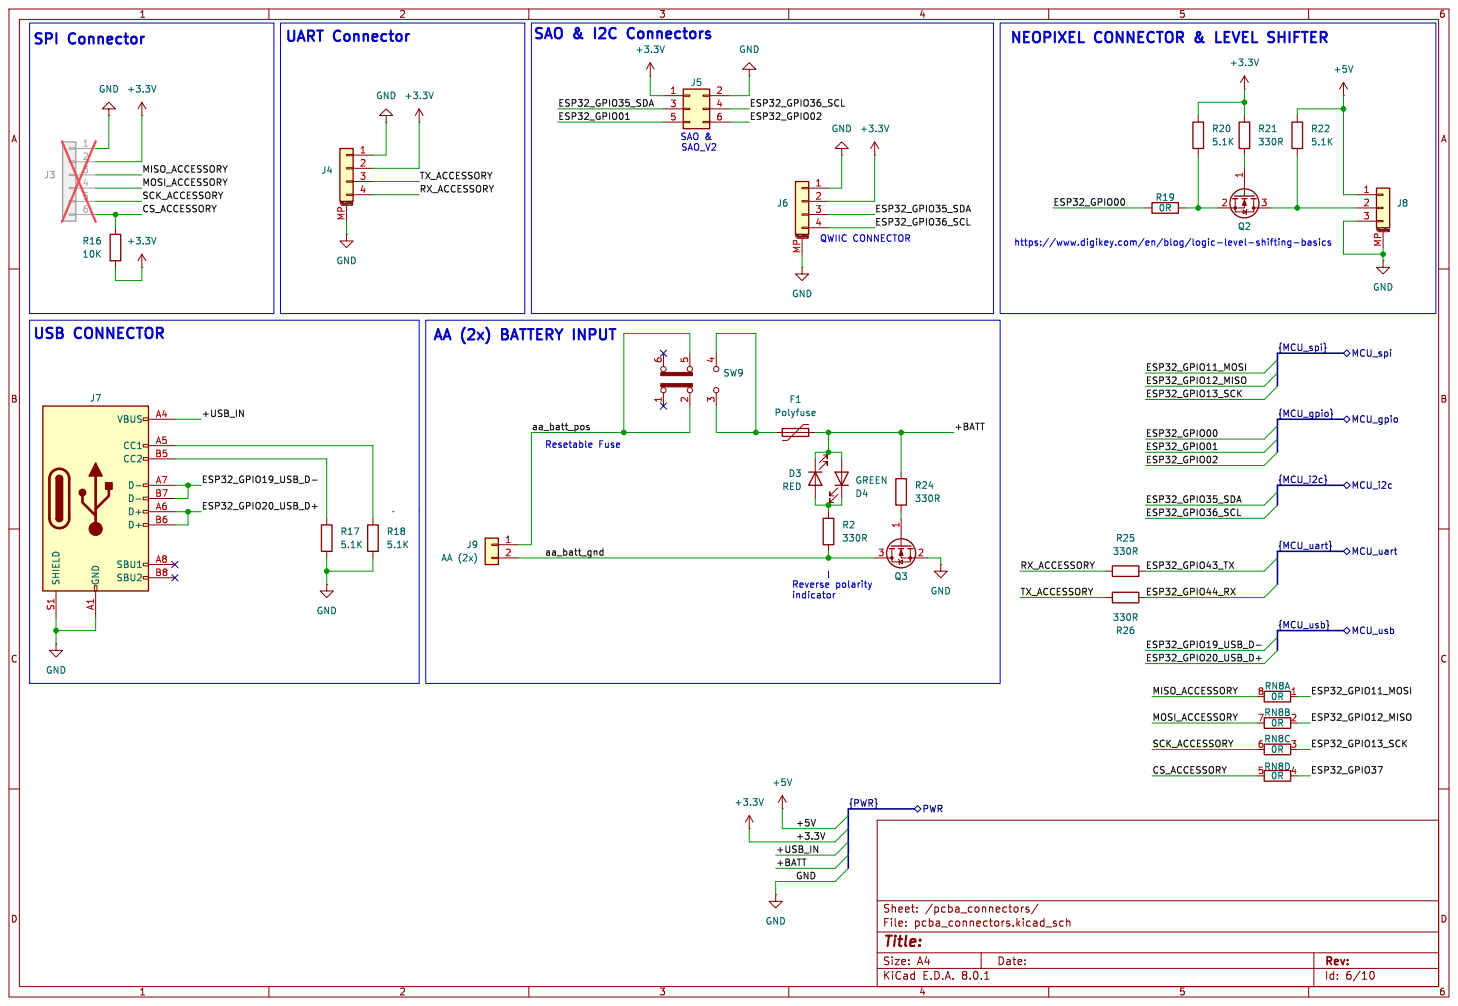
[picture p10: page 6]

Resetable Fuse USB CONNECTOR
J7 GND

Id: 6/10 Title: File: pcba_connectors.kicad_sch Sheet: /pcba_connectors/

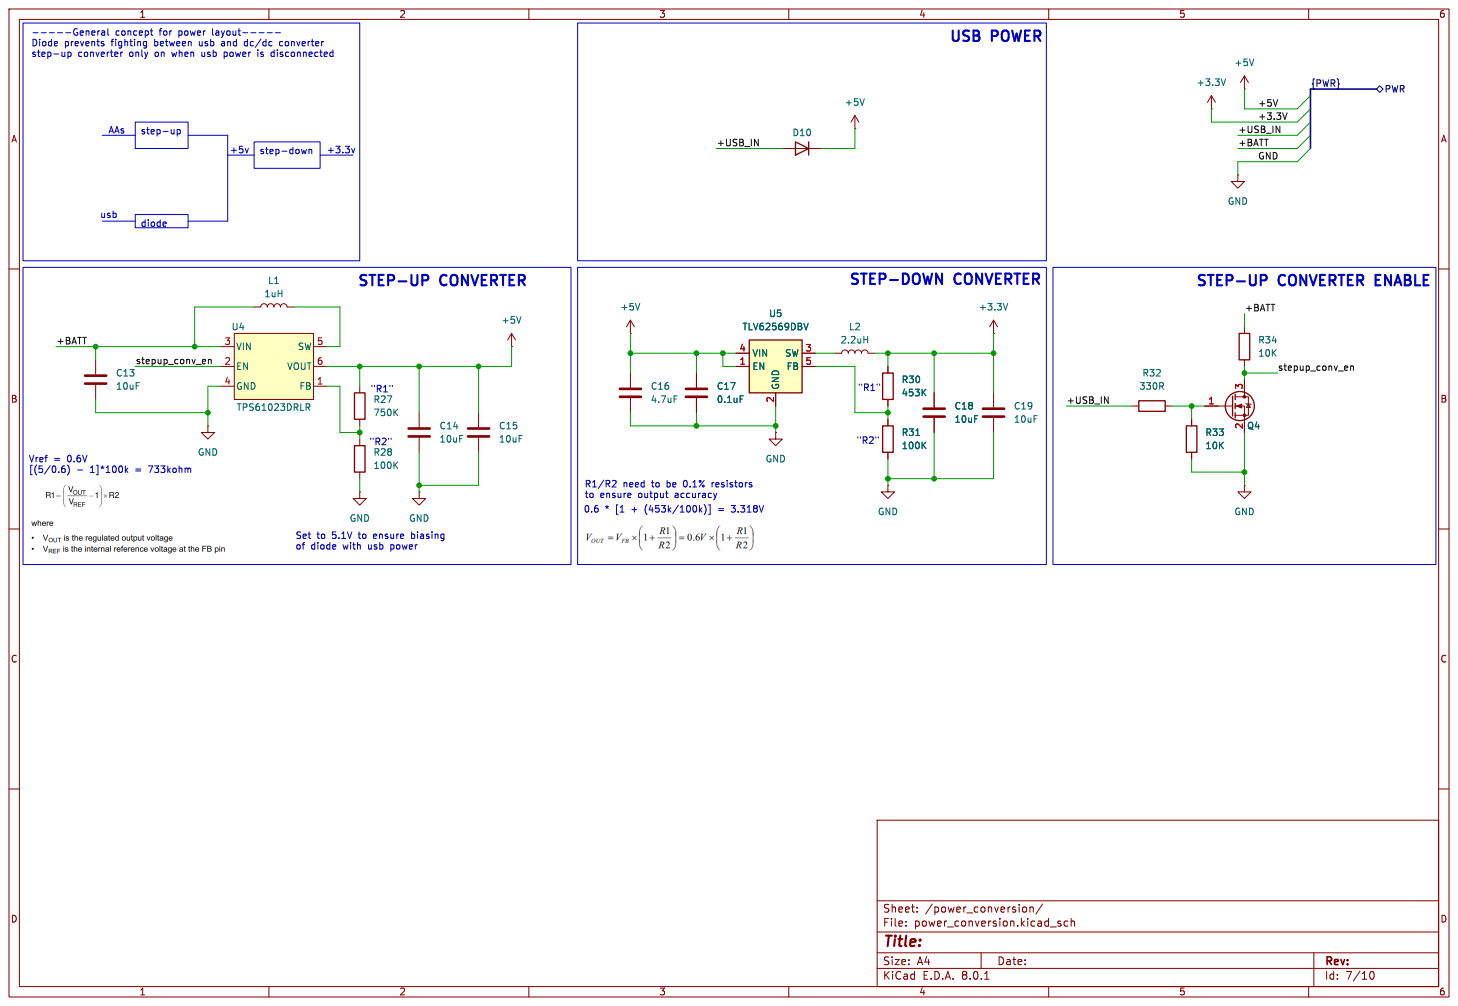
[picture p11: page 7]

of diode with usb power usb

2 SW 3 VIN 4 FB 5 U5 TLV62569DBV GND

R1/R2 need to be 0.1% resistors

Id: 7/10 Title: File: power_conversion.kicad_sch Sheet: /power_conversion/

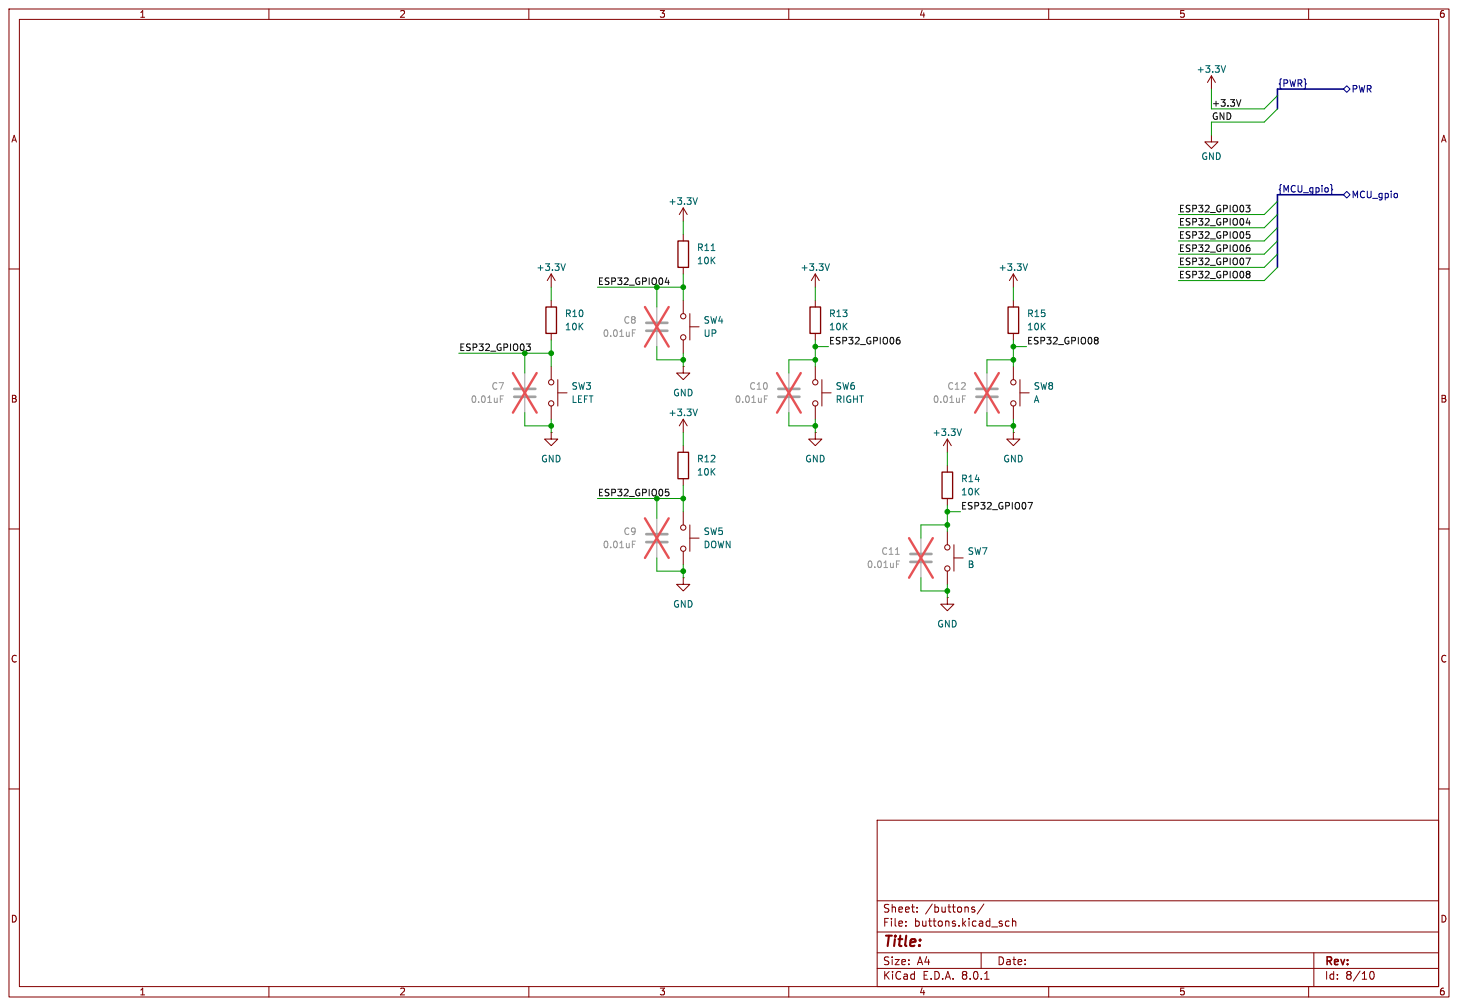
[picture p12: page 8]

Id: 8/10 Title: File: buttons.kicad_sch Sheet: /buttons/

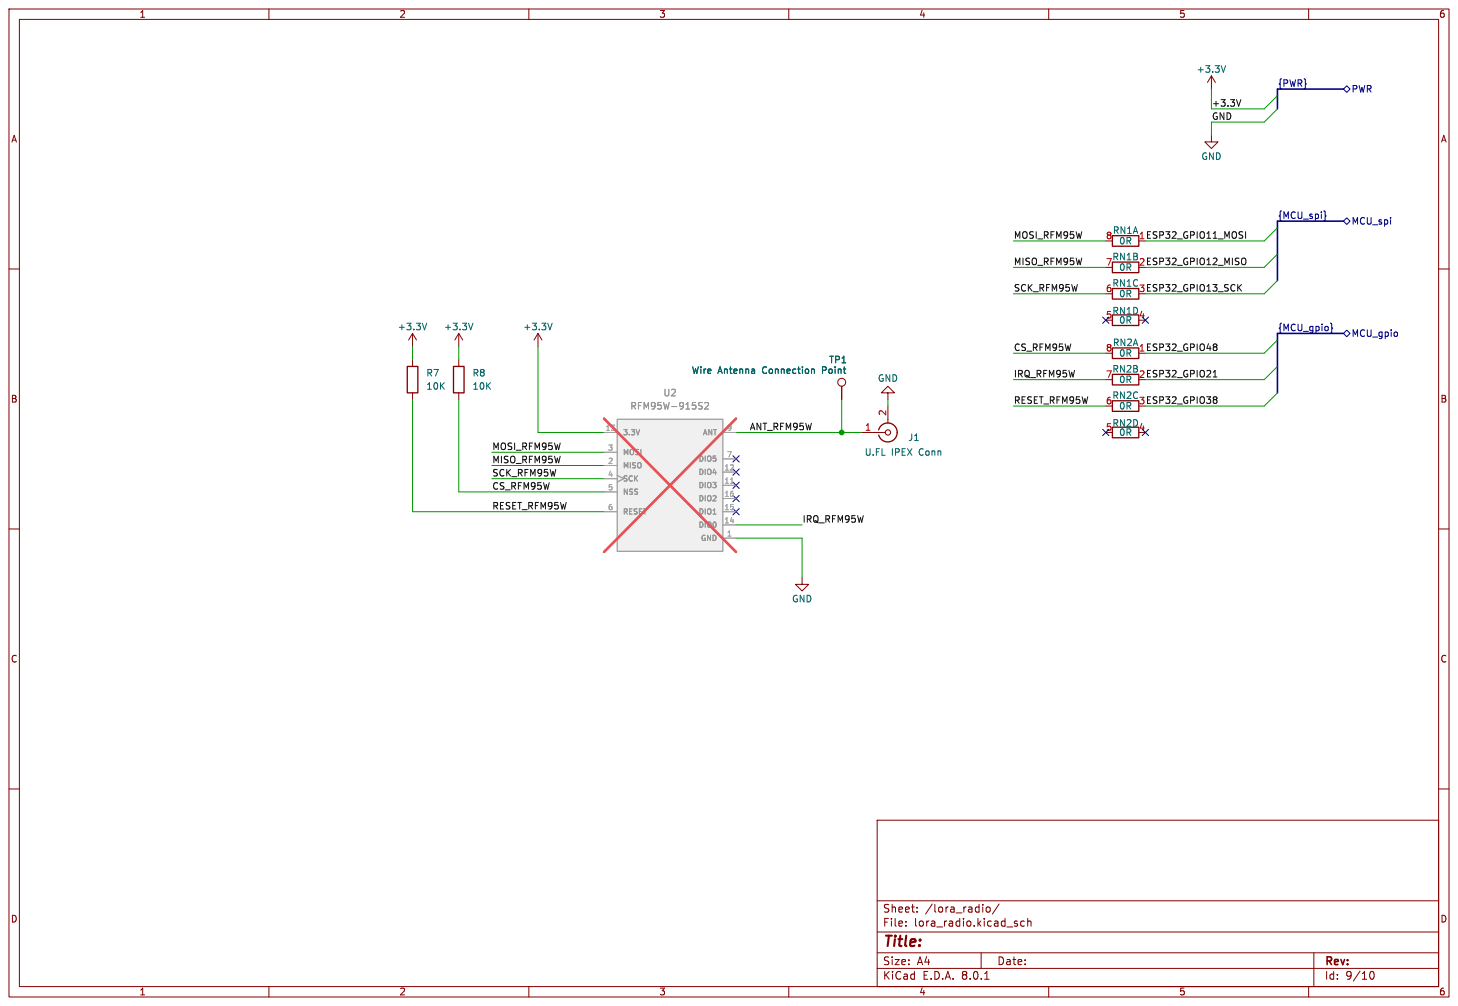
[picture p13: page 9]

J1 U.FL IPEX Conn GND

Id: 9/10 Title: File: lora_radio.kicad_sch Sheet: /lora_radio/

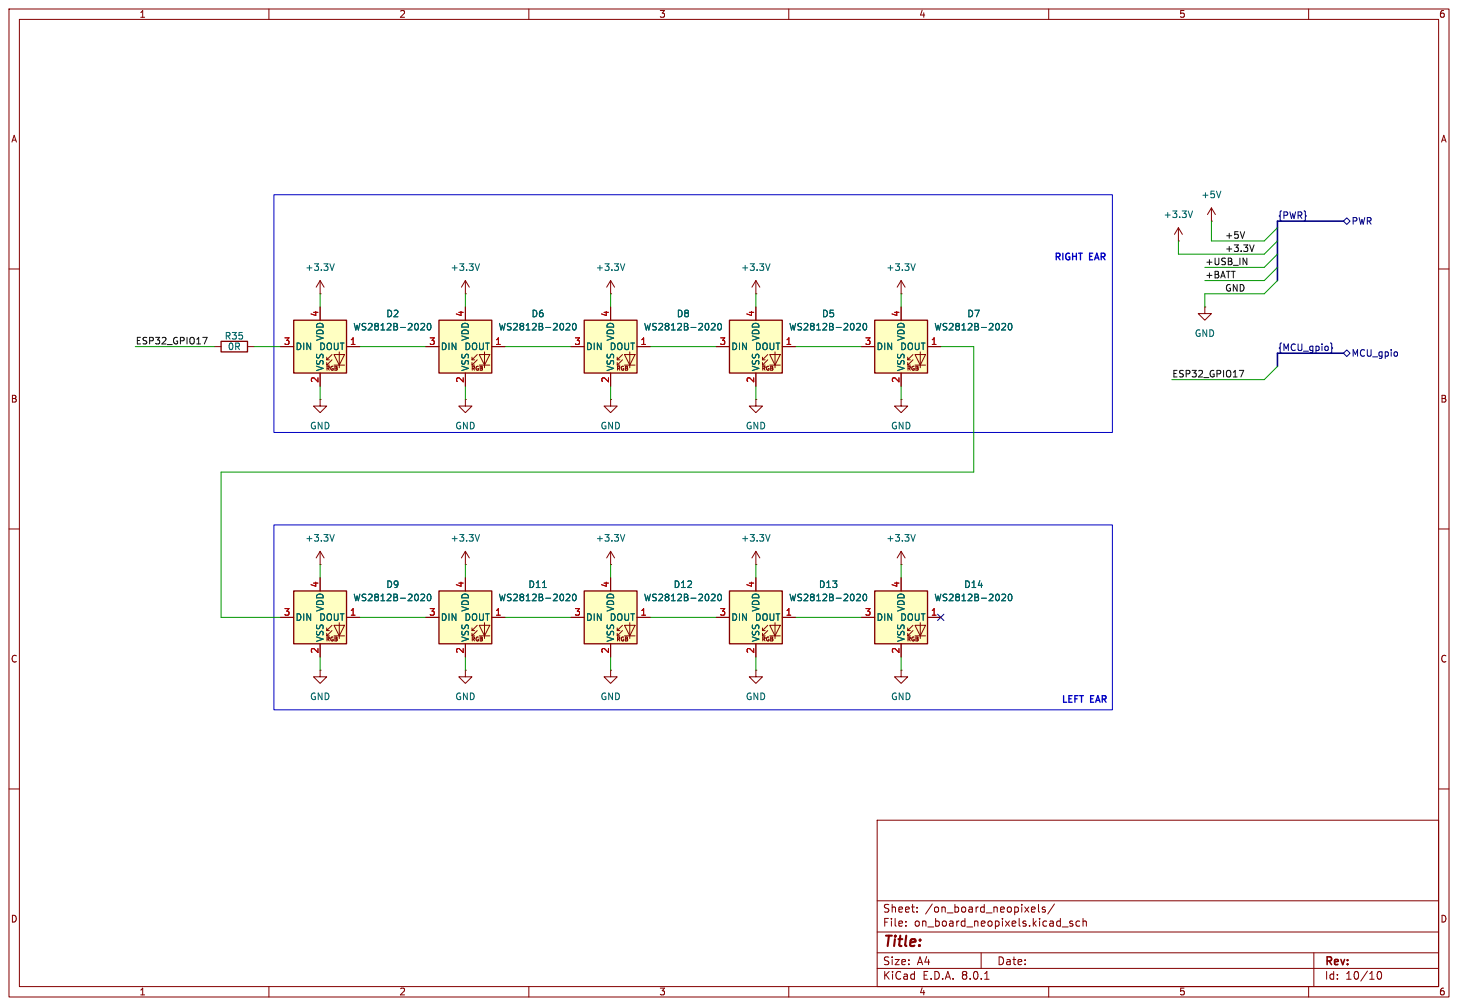
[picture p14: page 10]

Id: 10/10 Title: File: on_board_neopixels.kicad_sch Sheet: /on_board_neopixels/

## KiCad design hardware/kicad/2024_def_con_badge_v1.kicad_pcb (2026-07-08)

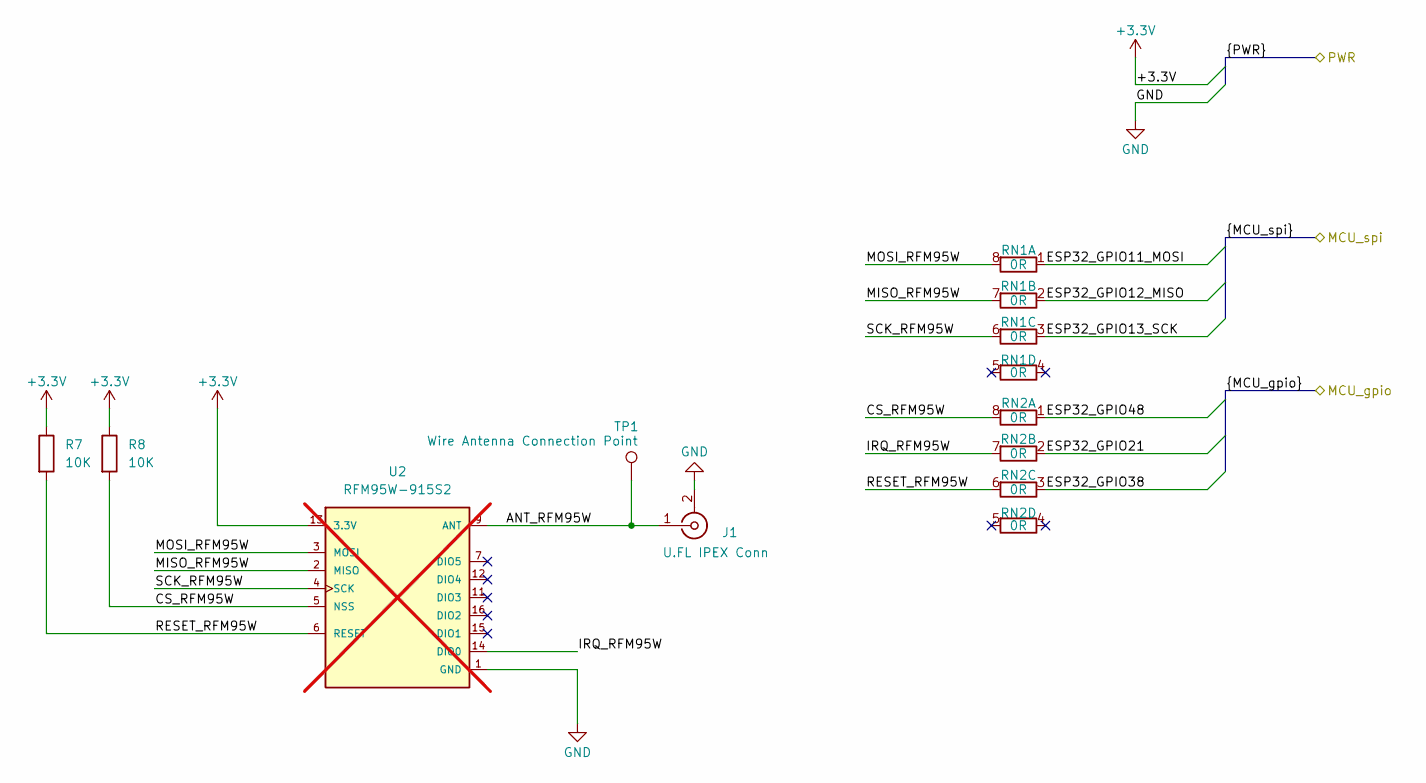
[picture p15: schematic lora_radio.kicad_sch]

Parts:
J1: U.FL IPEX Conn; LCSC_U.FL_Hirose_U.FL-R-SMT-1_Vertical; LCSC Part # C5137195
R7, R8: 10K; R_0603_1608Metric_Pad0.98x0.95mm_HandSolder; LCSC Part # C98220
RN1, RN2: 0R; YAGEO_R_ARRAY_4_YC_FAM; LCSC Part # C327053
TP1: Wire Antenna Connection Point; TestPoint_THTPad_D2.0mm_Drill1.0mm
U2: RFM95W-915S2; XCVR_RFM95W-915S2; not fitted

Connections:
+3.3V: R7.1, R8.1, U2.13 (3.3V); also elsewhere on the board
/buttons/ESP32_GPIO21: RN2.2 (R2.1); also elsewhere on the board
/buttons/ESP32_GPIO38: RN2.3 (R3.1); also elsewhere on the board
/buttons/ESP32_GPIO48: RN2.1 (R1.1); also elsewhere on the board
/display/ESP32_GPIO11_MOSI: RN1.1 (R1.1); also elsewhere on the board
/display/ESP32_GPIO12_MISO: RN1.2 (R2.1); also elsewhere on the board
/display/ESP32_GPIO13_SCK: RN1.3 (R3.1); also elsewhere on the board
/lora_radio/ANT_RFM95W: J1.1 (In), TP1.1, U2.9 (ANT)
/lora_radio/CS_RFM95W: R8.2, RN2.8 (R1.2), U2.5 (NSS)
/lora_radio/IRQ_RFM95W: RN2.7 (R2.2), U2.14 (DIO0)
/lora_radio/MISO_RFM95W: RN1.7 (R2.2), U2.2 (MISO)
/lora_radio/MOSI_RFM95W: RN1.8 (R1.2), U2.3 (MOSI)
/lora_radio/RESET_RFM95W: R7.2, RN2.6 (R3.2), U2.6 (RESET)
/lora_radio/SCK_RFM95W: RN1.6 (R3.2), U2.4 (SCK)
GND: J1.2 (Ext), U2.1 (GND), U2.8 (GND), U2.10 (GND); also elsewhere on the board

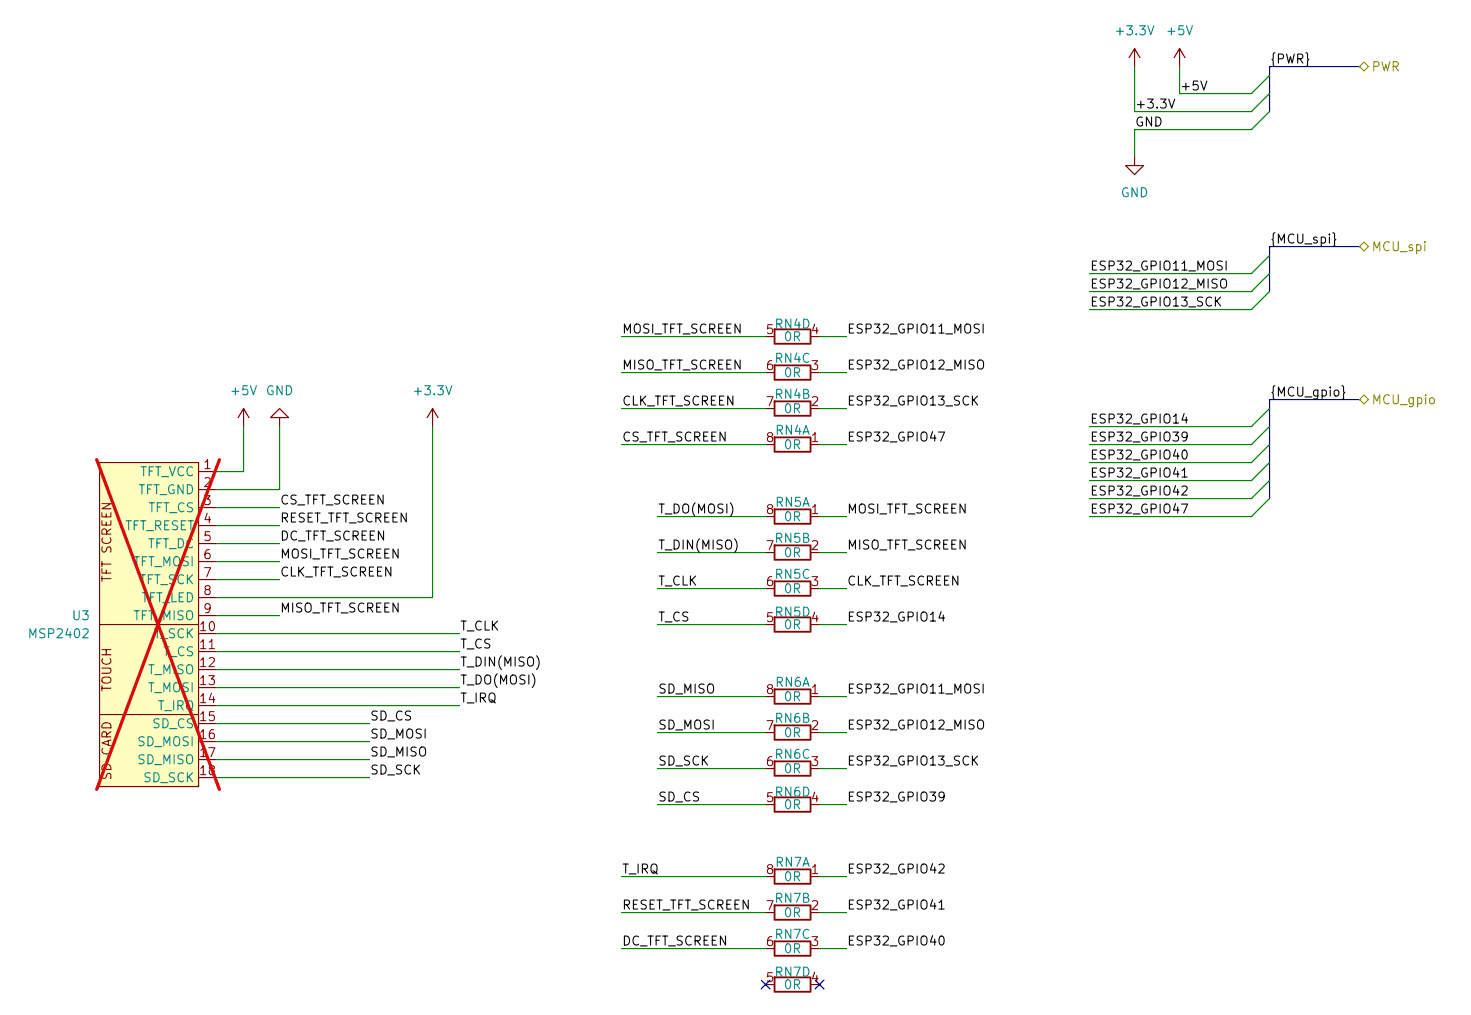
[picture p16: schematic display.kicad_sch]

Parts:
RN4, RN5, RN6, RN7: 0R; YAGEO_R_ARRAY_4_YC_FAM; LCSC Part # C327053
U3: MSP2402; LCD_2_4in_PCB_MOUNTED_THRU_HOLE; not fitted

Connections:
+3.3V: U3.8 (TFT_LED); also elsewhere on the board
+5V: U3.1 (TFT_VCC); also elsewhere on the board
/buttons/ESP32_GPIO14: RN5.4 (R4.1); also elsewhere on the board
/buttons/ESP32_GPIO39: RN6.4 (R4.1); also elsewhere on the board
/buttons/ESP32_GPIO40: RN7.3 (R3.1); also elsewhere on the board
/buttons/ESP32_GPIO41: RN7.2 (R2.1); also elsewhere on the board
/buttons/ESP32_GPIO42: RN7.1 (R1.1); also elsewhere on the board
/buttons/ESP32_GPIO47: RN4.1 (R1.1); also elsewhere on the board
/display/CLK_TFT_SCREEN: RN4.7 (R2.2), RN5.3 (R3.1), U3.7 (TFT_SCK)
/display/CS_TFT_SCREEN: RN4.8 (R1.2), U3.3 (TFT_CS)
/display/DC_TFT_SCREEN: RN7.6 (R3.2), U3.5 (TFT_DC)
/display/ESP32_GPIO11_MOSI: RN4.4 (R4.1), RN6.1 (R1.1); also elsewhere on the board
/display/ESP32_GPIO12_MISO: RN4.3 (R3.1), RN6.2 (R2.1); also elsewhere on the board
/display/ESP32_GPIO13_SCK: RN4.2 (R2.1), RN6.3 (R3.1); also elsewhere on the board
/display/MISO_TFT_SCREEN: RN4.6 (R3.2), RN5.2 (R2.1), U3.9 (TFT_MISO)
/display/MOSI_TFT_SCREEN: RN4.5 (R4.2), RN5.1 (R1.1), U3.6 (TFT_MOSI)
/display/RESET_TFT_SCREEN: RN7.7 (R2.2), U3.4 (TFT_RESET)
/display/SD_CS: RN6.5 (R4.2), U3.15 (SD_CS)
/display/SD_MISO: RN6.8 (R1.2), U3.17 (SD_MISO)
/display/SD_MOSI: RN6.7 (R2.2), U3.16 (SD_MOSI)
/display/SD_SCK: RN6.6 (R3.2), U3.18 (SD_SCK)
/display/T_CLK: RN5.6 (R3.2), U3.10 (T_SCK)
/display/T_CS: RN5.5 (R4.2), U3.11 (T_CS)
/display/T_DIN(MISO): RN5.7 (R2.2), U3.12 (T_MISO)
/display/T_DO(MOSI): RN5.8 (R1.2), U3.13 (T_MOSI)
/display/T_IRQ: RN7.8 (R1.2), U3.14 (T_IRQ)
GND: U3.2 (TFT_GND); also elsewhere on the board

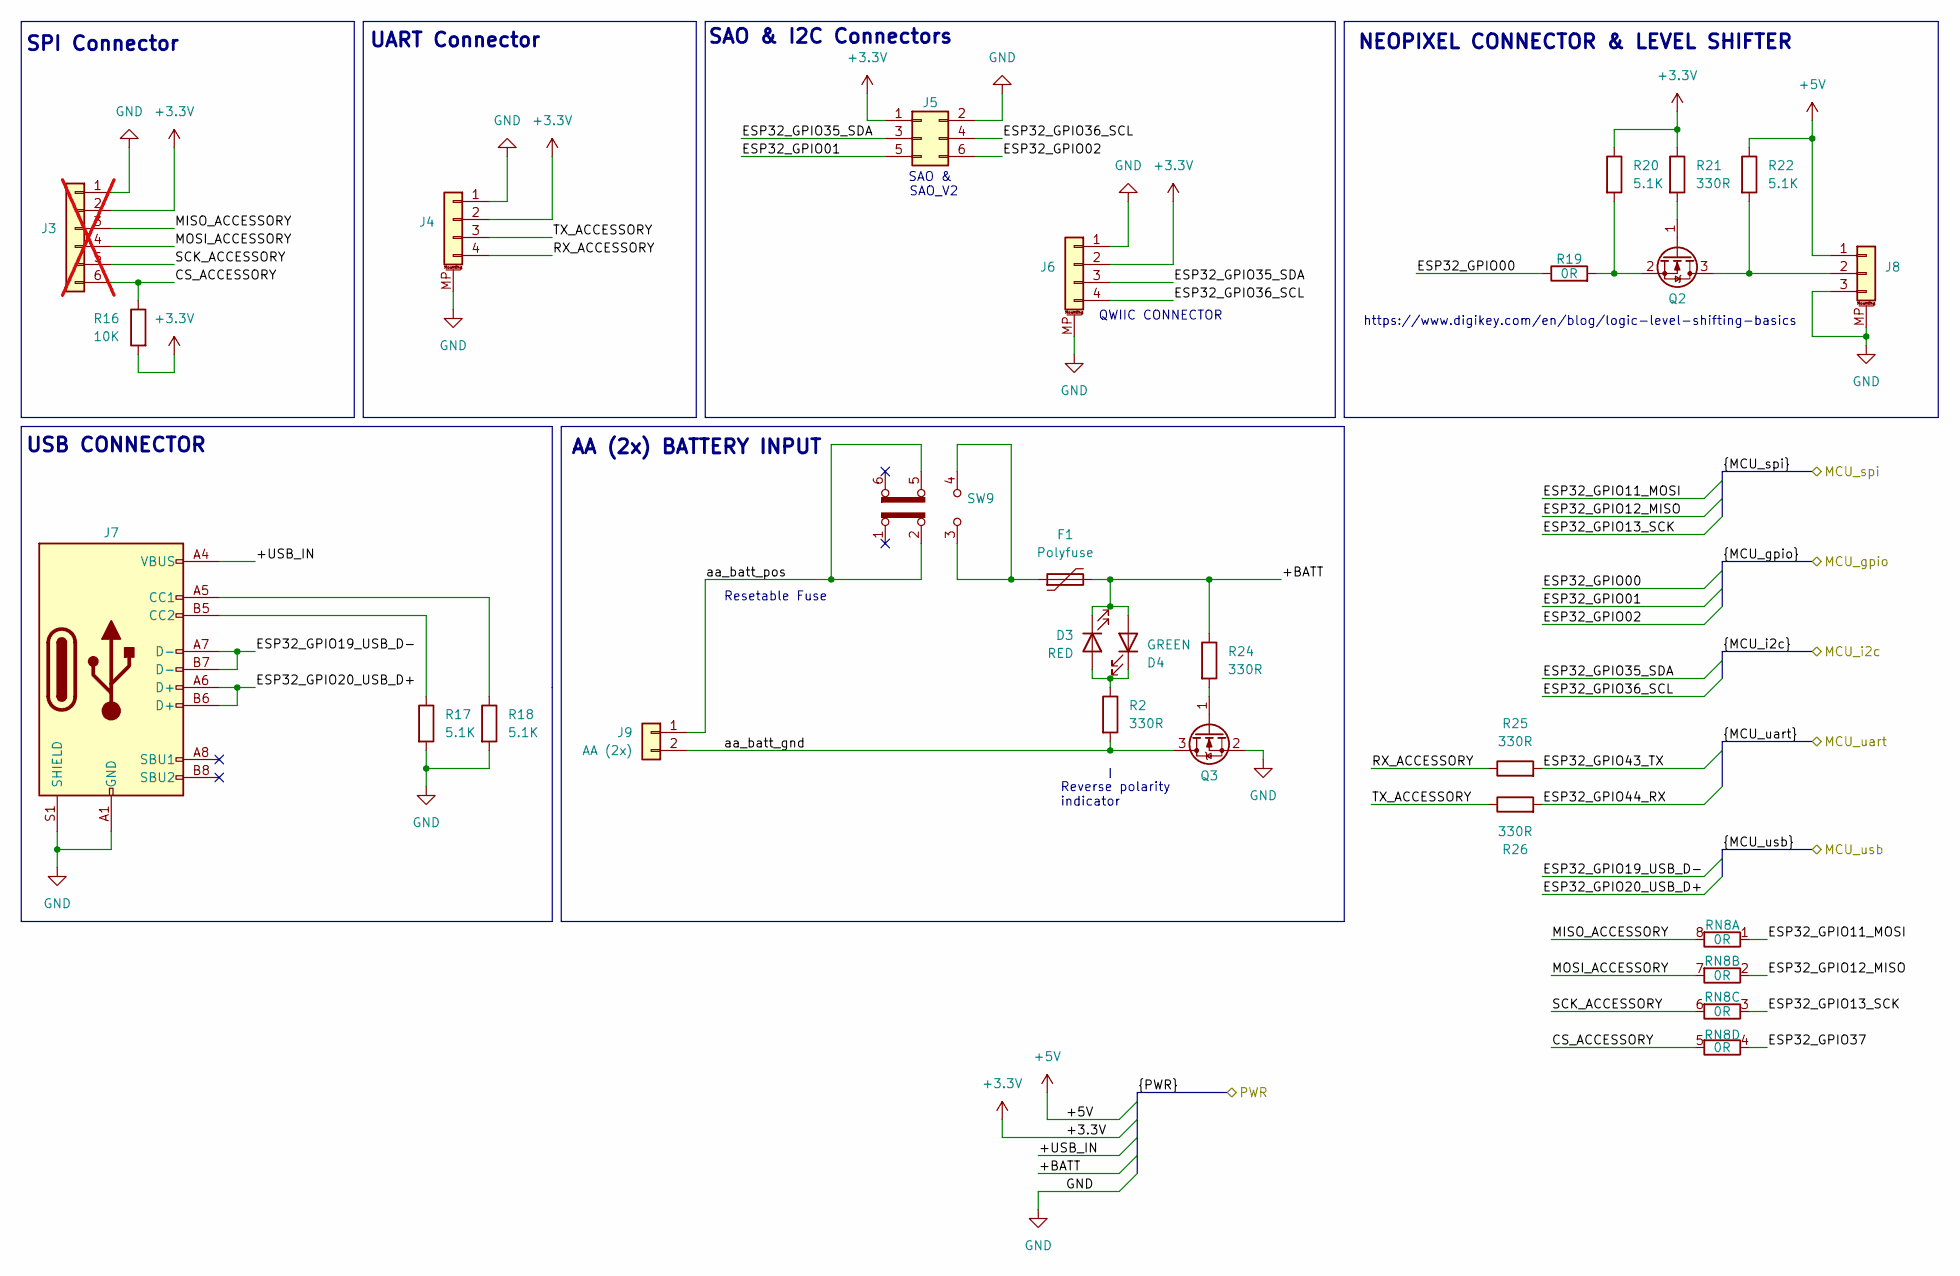
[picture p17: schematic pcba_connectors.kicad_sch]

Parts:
D3: RED; LED_0805_2012Metric_Pad1.15x1.40mm_HandSolder; LCSC Part # C94868
D4: GREEN; LED_0805_2012Metric_Pad1.15x1.40mm_HandSolder; LCSC Part # C98221
F1: Polyfuse; Fuse_1206_3216Metric_Pad1.42x1.75mm_HandSolder; LCSC Part # C883133
J3: Conn_01x06; PinHeader_1x06_P2.54mm_Vertical; not fitted
J4, J6: Conn_01x04_MountingPin; QWIIC_CONNECTOR_GENERIC_1x04-1MP_P1.00mm_Horizontal; LCSC Part # C7430446
J5: Conn_02x03_Odd_Even; LCSC_PinSocket_2x03_P2.54mm_Vertical; LCSC Part # C2897404
J7: USB_C_Receptacle_USB2.0_16P; LCSC_USB_C_Receptacle_HCTL_HC-TYPE-C-16P-01A; LCSC Part # C2894897
J8: Conn_01x03_MountingPin; LCSC_JST_PH_S3B-PH-SM4-TB_1x03-1MP_P2.00mm_Horizontal; LCSC Part # C2905020
J9: AA (2x); BatteryHolder_Keystone_2462_2xAA
Q2, Q3: Q_NMOS_GSD; LCSC_SOT-23; LCSC Part # C91714
R2, R21, R24, R25, R26: 330R; R_0603_1608Metric_Pad0.98x0.95mm_HandSolder; LCSC Part # C105881
R16: 10K; R_0603_1608Metric_Pad0.98x0.95mm_HandSolder; LCSC Part # C98220
R17, R18, R20, R22: 5.1K; R_0603_1608Metric_Pad0.98x0.95mm_HandSolder; LCSC Part # C105580
R19: 0R; R_0603_1608Metric_Pad0.98x0.95mm_HandSolder; LCSC Part # C116699
RN8: 0R; YAGEO_R_ARRAY_4_YC_FAM; LCSC Part # C327053
SW9: SW_Slide_DPDT; JLC_K3-2245S-K1; LCSC Part # C223861

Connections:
+3.3V: J3.2, J4.2, J5.1, J6.2, R16.2, R20.1, R21.1; also elsewhere on the board
+5V: J8.1, R22.1; also elsewhere on the board
/buttons/+BATT: D3.1 (K), D4.2 (A), F1.2, R24.1; also elsewhere on the board
/buttons/+USB_IN: J7.A4 (VBUS), J7.A9 (VBUS), J7.B4 (VBUS), J7.B9 (VBUS); also elsewhere on the board
/buttons/ESP32_GPIO00: R19.1; also elsewhere on the board
/buttons/ESP32_GPIO01: J5.5; also elsewhere on the board
/buttons/ESP32_GPIO02: J5.6; also elsewhere on the board
/buttons/ESP32_GPIO37: RN8.4 (R4.1); also elsewhere on the board
/display/ESP32_GPIO11_MOSI: RN8.1 (R1.1); also elsewhere on the board
/display/ESP32_GPIO12_MISO: RN8.2 (R2.1); also elsewhere on the board
/display/ESP32_GPIO13_SCK: RN8.3 (R3.1); also elsewhere on the board
/mcu_block/ESP32_GPIO19_USB_D-: J7.A7 (D-), J7.B7 (D-); also elsewhere on the board
/mcu_block/ESP32_GPIO20_USB_D+: J7.A6 (D+), J7.B6 (D+); also elsewhere on the board
/mcu_block/ESP32_GPIO35_SDA: J5.3, J6.3; also elsewhere on the board
/mcu_block/ESP32_GPIO36_SCL: J5.4, J6.4; also elsewhere on the board
/mcu_block/ESP32_GPIO43_TX: R25.2; also elsewhere on the board
/mcu_block/ESP32_GPIO44_RX: R26.2; also elsewhere on the board
/pcba_connectors/CS_ACCESSORY: J3.6, R16.1, RN8.5 (R4.2)
/pcba_connectors/MISO_ACCESSORY: J3.3, RN8.8 (R1.2)
/pcba_connectors/MOSI_ACCESSORY: J3.4, RN8.7 (R2.2)
/pcba_connectors/RX_ACCESSORY: J4.4, R25.1
/pcba_connectors/SCK_ACCESSORY: J3.5, RN8.6 (R3.2)
/pcba_connectors/TX_ACCESSORY: J4.3, R26.1
/pcba_connectors/aa_batt_gnd: J9.2, Q3.3 (D), R2.2
/pcba_connectors/aa_batt_pos: J9.1, SW9.2 (B), SW9.5 (B)
GND: J3.1, J4.1, J4.MP (MountPin), J5.2, J6.1, J6.MP (MountPin), J7.A1 (GND), J7.A12 (GND), J7.B1 (GND), J7.B12 (GND), J7.S1 (SHIELD), J8.3, J8.MP (MountPin), Q3.2 (S), R17.2, R18.2; also elsewhere on the board
unnamed: D3.2 (A), D4.1 (K), R2.1
unnamed: F1.1, SW9.3 (C), SW9.4 (A)
unnamed: J7.A5 (CC1), R18.1
unnamed: J7.B5 (CC2), R17.1
unnamed: J8.2, Q2.3 (D), R22.2
unnamed: Q2.1 (G), R21.2
unnamed: Q2.2 (S), R19.2, R20.2
unnamed: Q3.1 (G), R24.2

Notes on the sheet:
https://www.digikey.com/en/blog/logic-level-shifting-basics
Reverse polarity indicator
SAO &
QWIIC CONNECTOR
NEOPIXEL CONNECTOR & LEVEL SHIFTER
UART Connector
SAO & I2C Connectors
SAO_V2
Resetable Fuse
USB CONNECTOR
SPI Connector
AA (2x) BATTERY INPUT

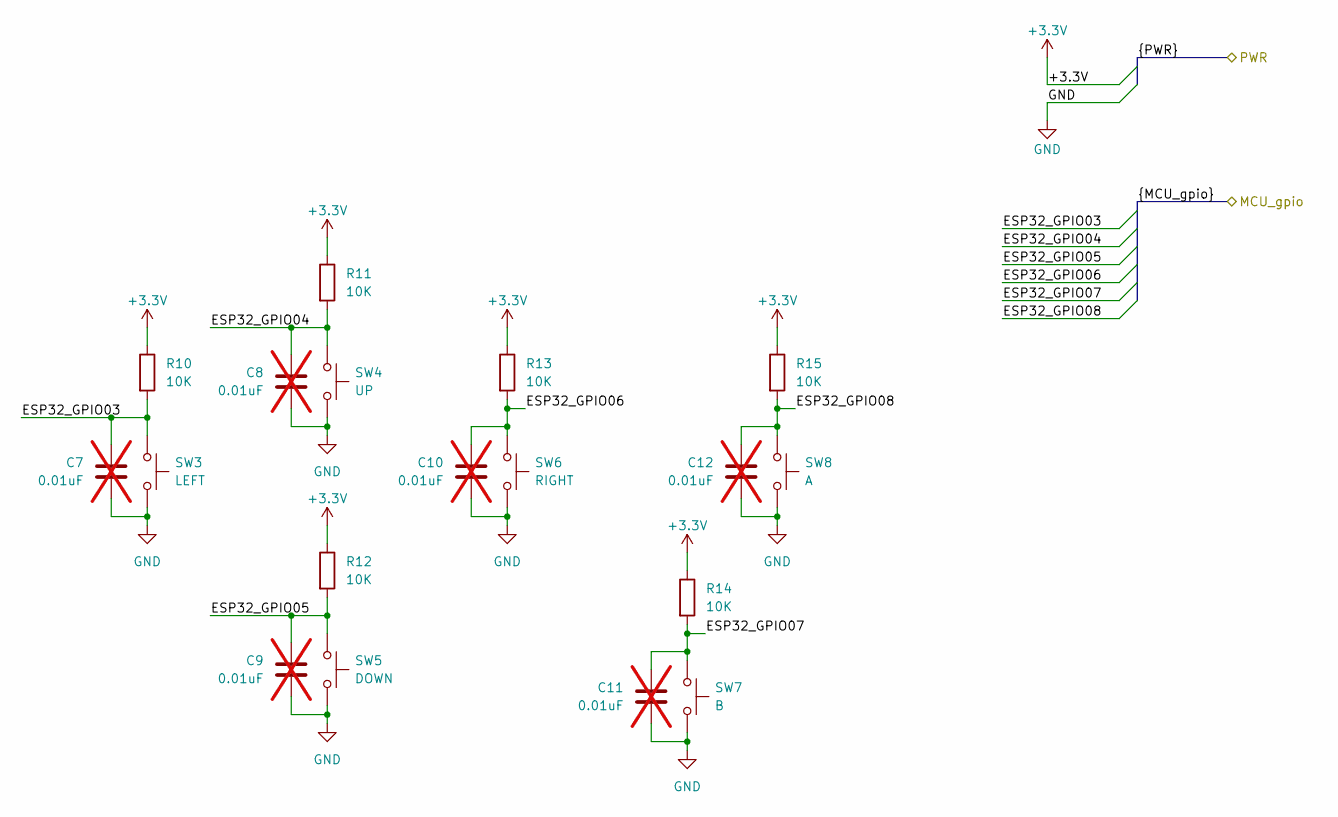
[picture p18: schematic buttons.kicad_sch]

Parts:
C7, C8, C9, C10, C11, C12: 0.01uF; C_0603_1608Metric_Pad1.08x0.95mm_HandSolder; LCSC Part # C92490; not fitted
R10, R11, R12, R13, R14, R15: 10K; R_0603_1608Metric_Pad0.98x0.95mm_HandSolder; LCSC Part # C98220
SW3: LEFT; JLC_TS-1080W-A7B3-D1; LCSC Part # C499306
SW4: UP; JLC_TS-1080W-A7B3-D1; LCSC Part # C499306
SW5: DOWN; JLC_TS-1080W-A7B3-D1; LCSC Part # C499306
SW6: RIGHT; JLC_TS-1080W-A7B3-D1; LCSC Part # C499306
SW7: B; JLC_TS-1080W-A7B3-D1; LCSC Part # C499306
SW8: A; JLC_TS-1080W-A7B3-D1; LCSC Part # C499306

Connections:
+3.3V: R10.1, R11.1, R12.1, R13.1, R14.1, R15.1; also elsewhere on the board
/buttons/ESP32_GPIO03: C7.1, R10.2, SW3.1; also elsewhere on the board
/buttons/ESP32_GPIO04: C8.1, R11.2, SW4.1; also elsewhere on the board
/buttons/ESP32_GPIO05: C9.1, R12.2, SW5.1; also elsewhere on the board
/buttons/ESP32_GPIO06: C10.1, R13.2, SW6.1; also elsewhere on the board
/buttons/ESP32_GPIO07: C11.1, R14.2, SW7.1; also elsewhere on the board
/buttons/ESP32_GPIO08: C12.1, R15.2, SW8.1; also elsewhere on the board
GND: C7.2, C8.2, C9.2, C10.2, C11.2, C12.2, SW3.2, SW4.2, SW5.2, SW6.2, SW7.2, SW8.2; also elsewhere on the board

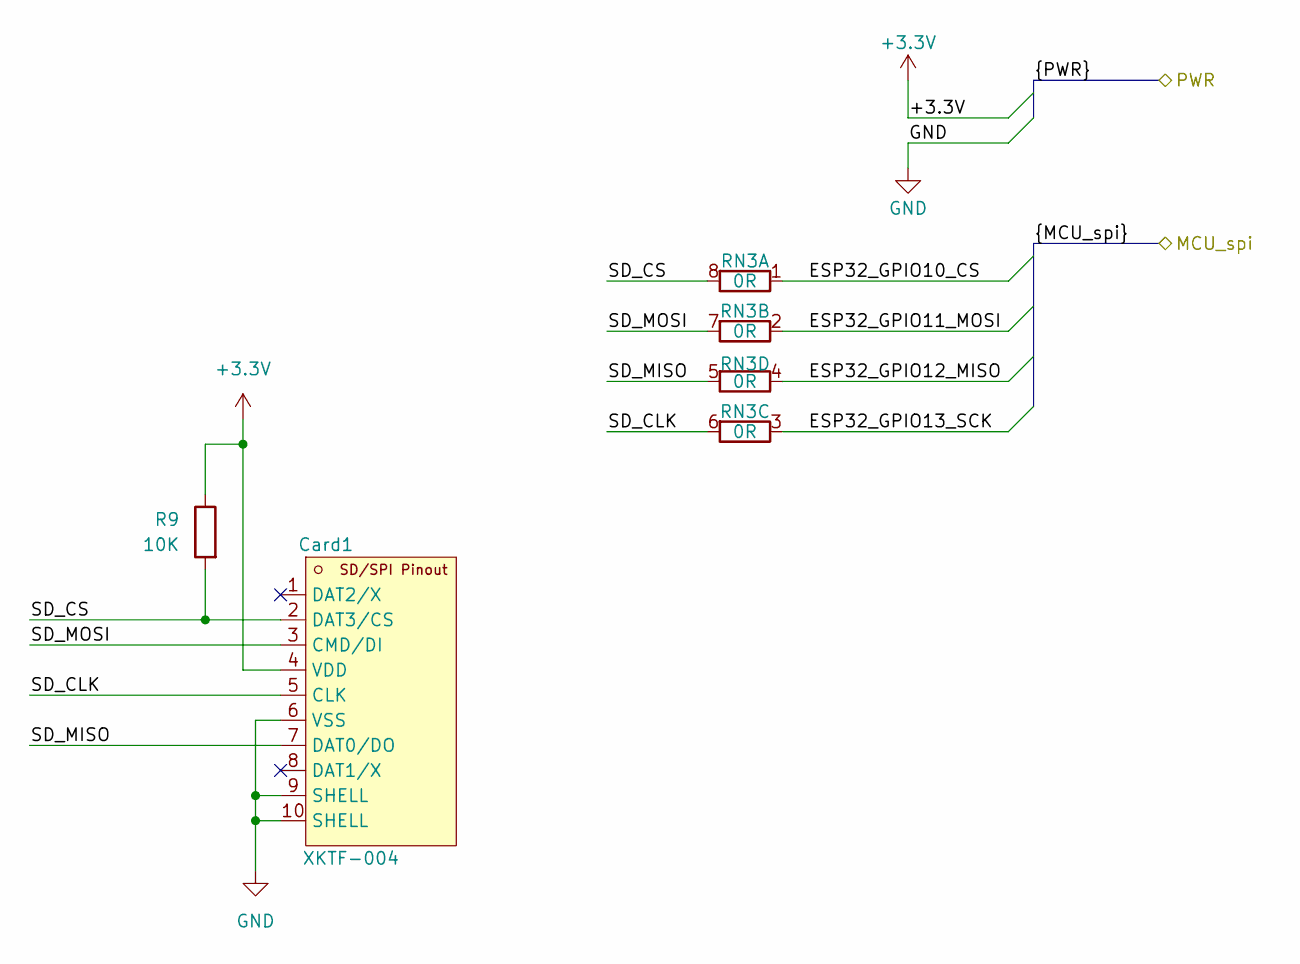
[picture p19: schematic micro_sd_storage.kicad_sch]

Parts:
Card1: XKTF-004; xkb_connection_XKTF-004; LCSC Part # C266612
R9: 10K; R_0603_1608Metric_Pad0.98x0.95mm_HandSolder; LCSC Part # C98220
RN3: 0R; YAGEO_R_ARRAY_4_YC_FAM; LCSC Part # C327053

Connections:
+3.3V: Card1.4 (VDD), R9.1; also elsewhere on the board
/display/ESP32_GPIO10_CS: RN3.1 (R1.1); also elsewhere on the board
/display/ESP32_GPIO11_MOSI: RN3.2 (R2.1); also elsewhere on the board
/display/ESP32_GPIO12_MISO: RN3.4 (R4.1); also elsewhere on the board
/display/ESP32_GPIO13_SCK: RN3.3 (R3.1); also elsewhere on the board
/micro_sd_storage/SD_CLK: Card1.5 (CLK), RN3.6 (R3.2)
/micro_sd_storage/SD_CS: Card1.2 (DAT3/CS), R9.2, RN3.8 (R1.2)
/micro_sd_storage/SD_MISO: Card1.7 (DAT0/DO), RN3.5 (R4.2)
/micro_sd_storage/SD_MOSI: Card1.3 (CMD/DI), RN3.7 (R2.2)
GND: Card1.6 (VSS), Card1.9 (SHELL), Card1.10 (SHELL); also elsewhere on the board

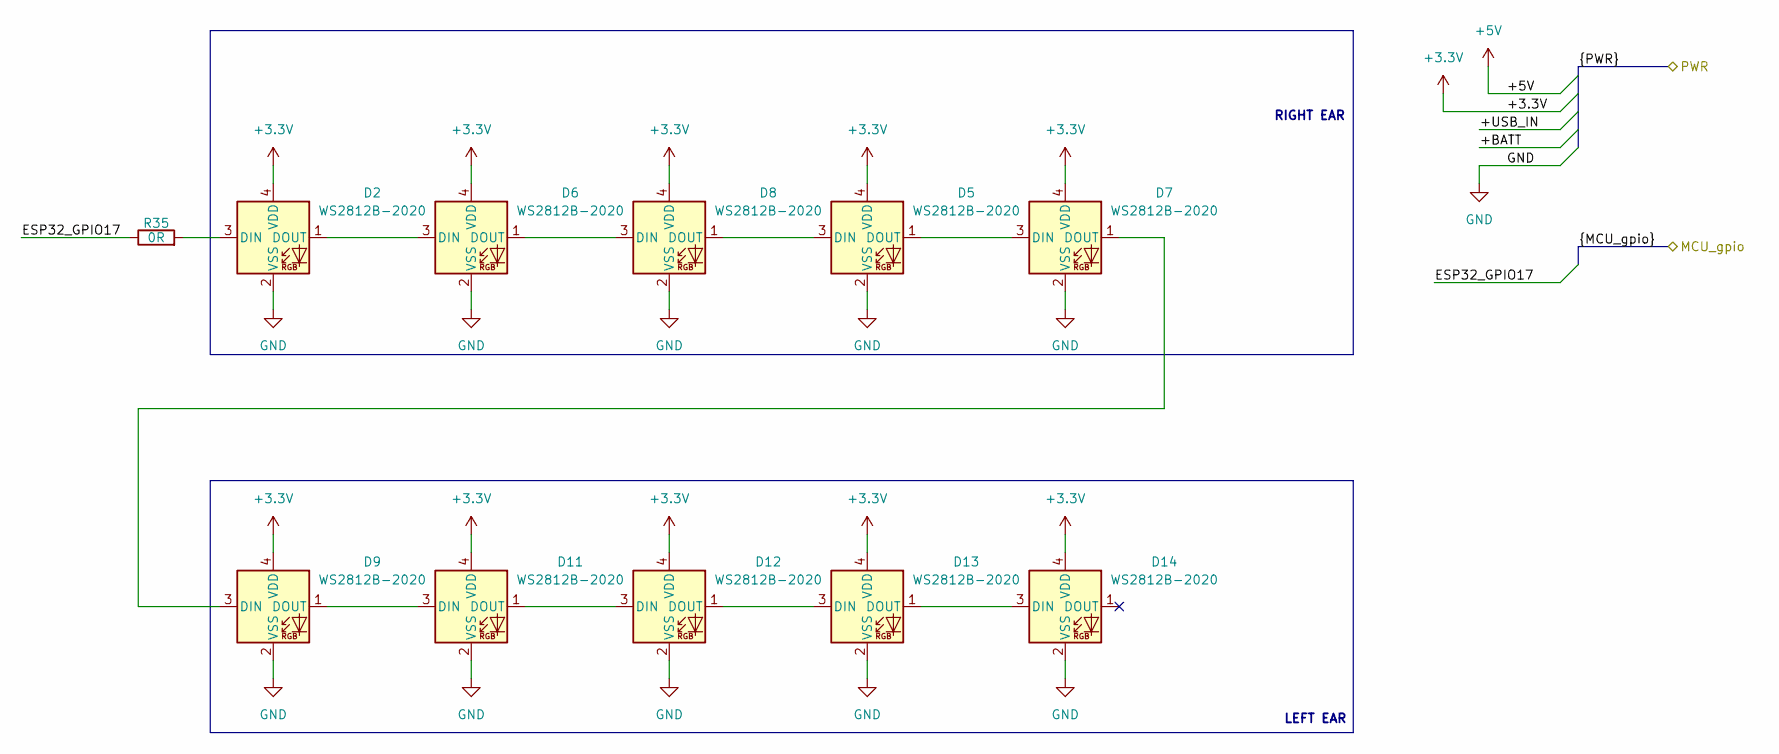
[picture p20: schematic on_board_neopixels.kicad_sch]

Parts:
D2, D5, D6, D7, D8, D9, D11, D12, D13, D14: WS2812B-2020; LED_WS2812B-2020_PLCC4_2.0x2.0mm; LCSC Part # C965555
R35: 0R; R_0603_1608Metric_Pad0.98x0.95mm_HandSolder; LCSC Part # C116699

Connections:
+3.3V: D2.4 (VDD), D5.4 (VDD), D6.4 (VDD), D7.4 (VDD), D8.4 (VDD), D9.4 (VDD), D11.4 (VDD), D12.4 (VDD), D13.4 (VDD), D14.4 (VDD); also elsewhere on the board
/buttons/ESP32_GPIO17: R35.1; also elsewhere on the board
GND: D2.2 (VSS), D5.2 (VSS), D6.2 (VSS), D7.2 (VSS), D8.2 (VSS), D9.2 (VSS), D11.2 (VSS), D12.2 (VSS), D13.2 (VSS), D14.2 (VSS); also elsewhere on the board
unnamed: D2.3 (DIN), R35.2
unnamed: D2.1 (DOUT), D6.3 (DIN)
unnamed: D5.3 (DIN), D8.1 (DOUT)
unnamed: D5.1 (DOUT), D7.3 (DIN)
unnamed: D6.1 (DOUT), D8.3 (DIN)
unnamed: D7.1 (DOUT), D9.3 (DIN)
unnamed: D9.1 (DOUT), D11.3 (DIN)
unnamed: D11.1 (DOUT), D12.3 (DIN)
unnamed: D12.1 (DOUT), D13.3 (DIN)
unnamed: D13.1 (DOUT), D14.3 (DIN)

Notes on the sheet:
RIGHT EAR
LEFT EAR

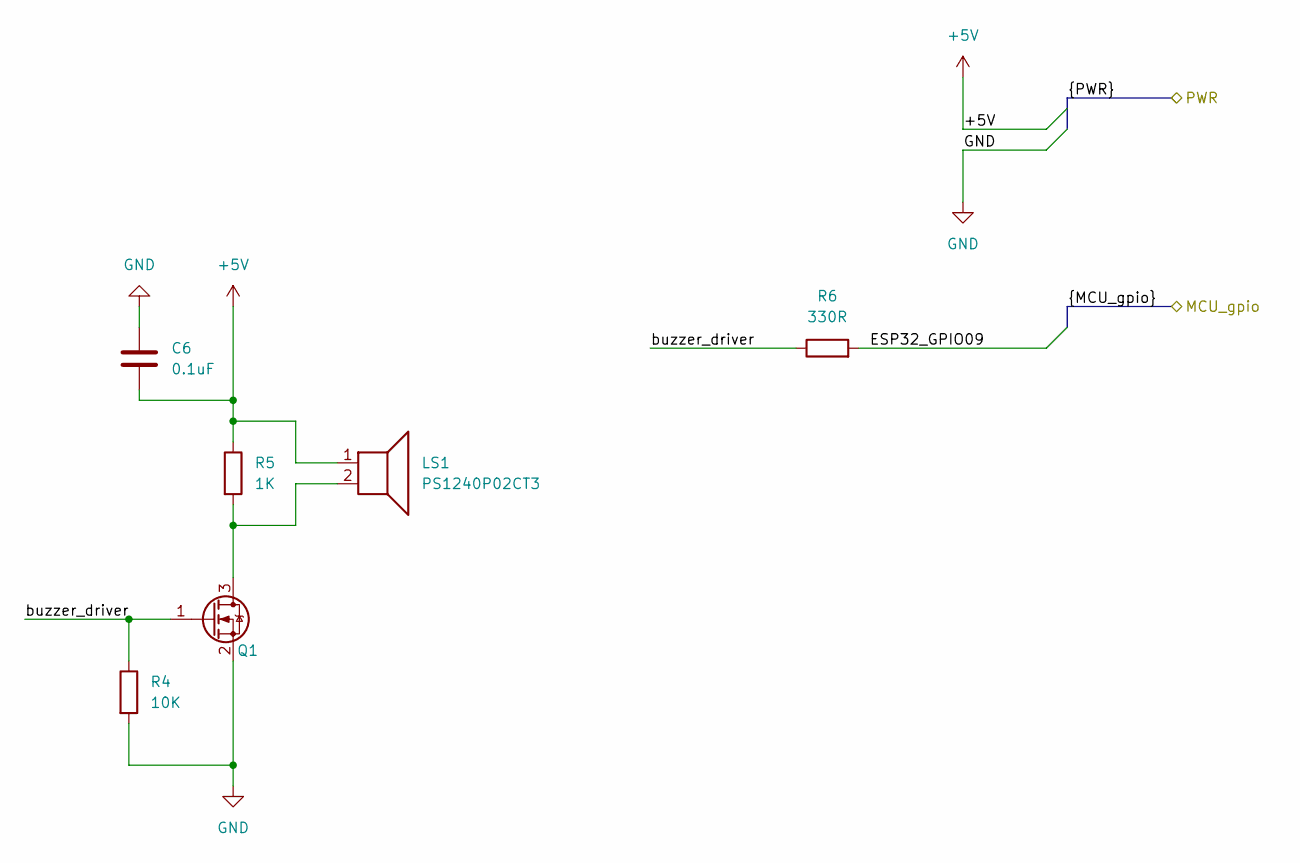
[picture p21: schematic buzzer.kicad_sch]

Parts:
C6: 0.1uF; C_0603_1608Metric_Pad1.08x0.95mm_HandSolder; LCSC Part # C92490
LS1: PS1240P02CT3; tdk_PS1240P02CT3_buzzer; LCSC Part # C76873
Q1: Q_NMOS_GSD; LCSC_SOT-23; LCSC Part # C91714
R4: 10K; R_0603_1608Metric_Pad0.98x0.95mm_HandSolder; LCSC Part # C98220
R5: 1K; R_0603_1608Metric_Pad0.98x0.95mm_HandSolder; LCSC Part # C22548
R6: 330R; R_0603_1608Metric_Pad0.98x0.95mm_HandSolder; LCSC Part # C105881

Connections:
+5V: C6.2, LS1.1, R5.1; also elsewhere on the board
/buttons/ESP32_GPIO09: R6.2; also elsewhere on the board
/buzzer/buzzer_driver: Q1.1 (G), R4.1, R6.1
GND: C6.1, Q1.2 (S), R4.2; also elsewhere on the board
unnamed: LS1.2, Q1.3 (D), R5.2

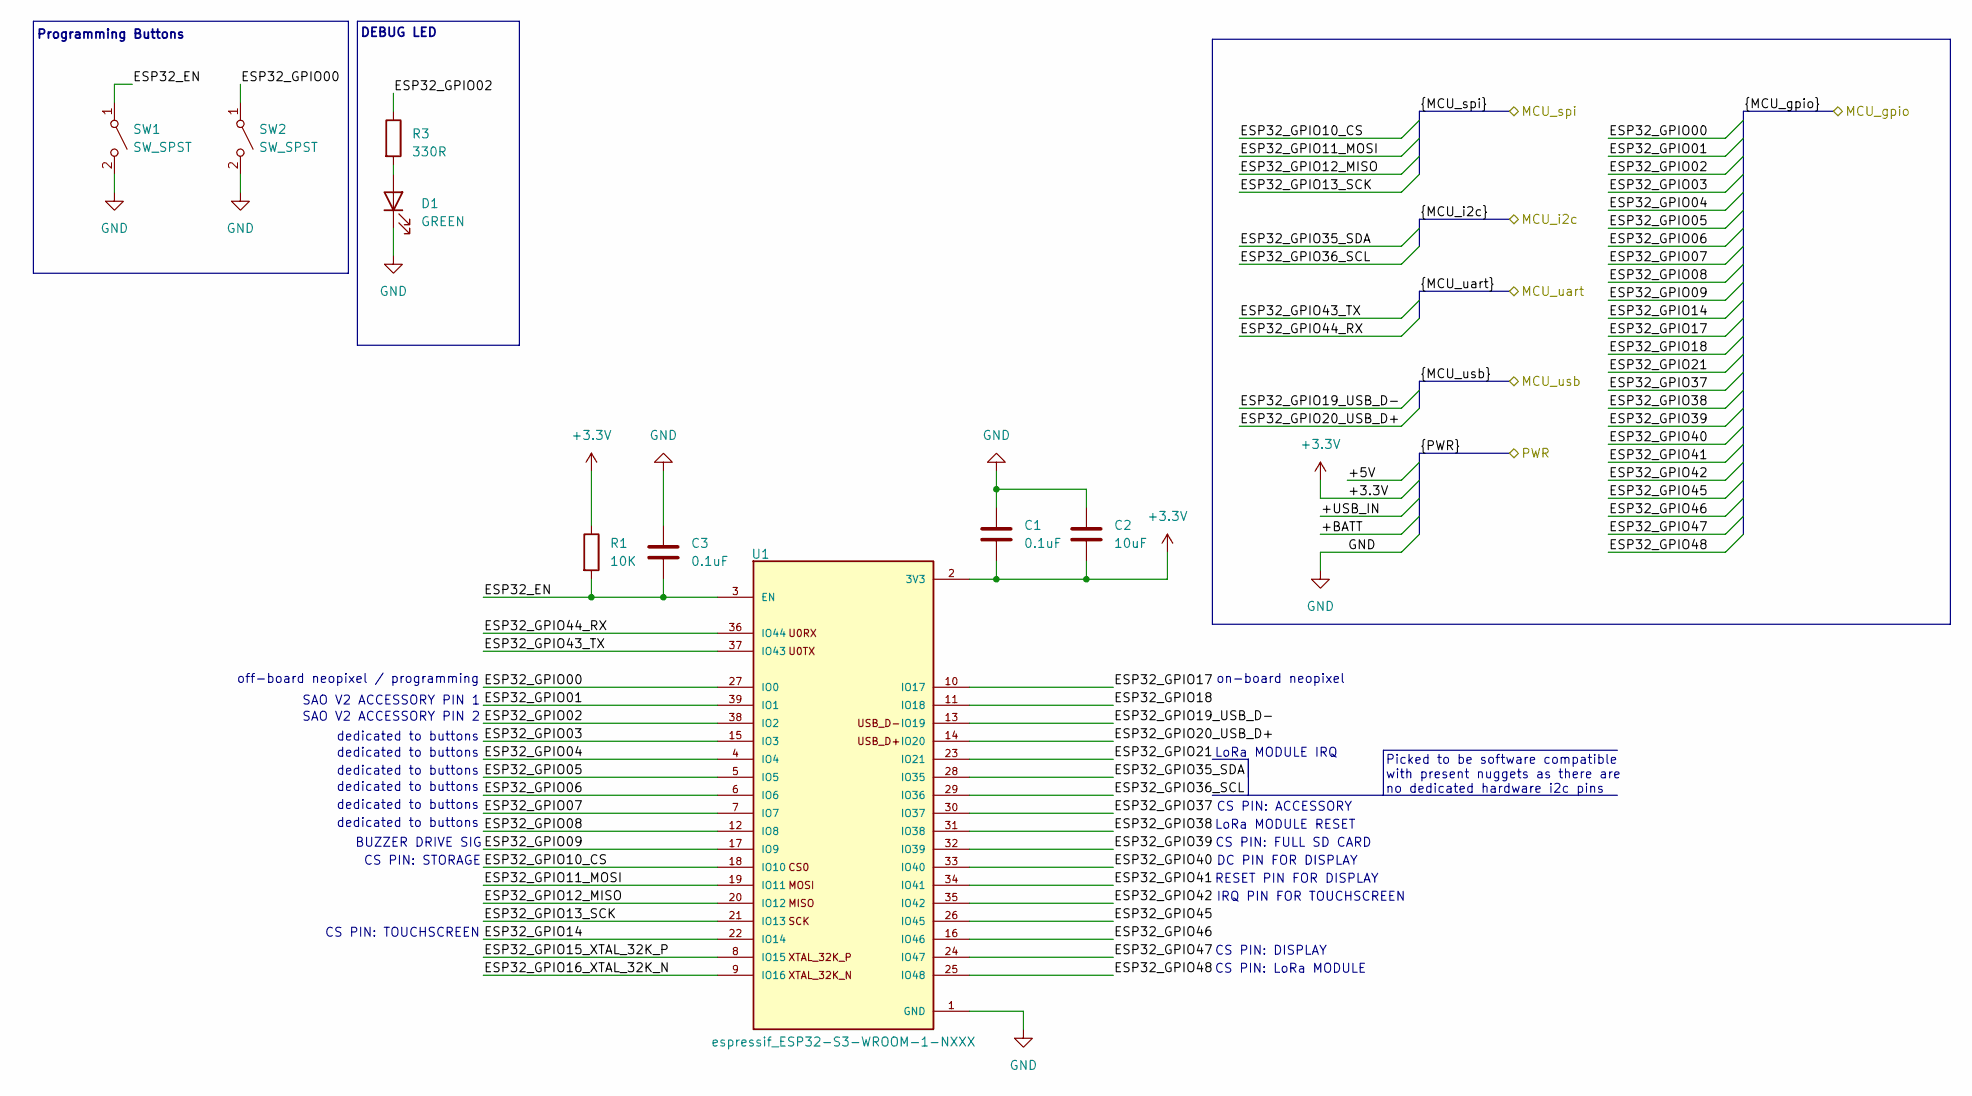
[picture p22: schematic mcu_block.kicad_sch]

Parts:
C1, C3: 0.1uF; C_0603_1608Metric_Pad1.08x0.95mm_HandSolder; LCSC Part # C92490
C2: 10uF; C_0603_1608Metric_Pad1.08x0.95mm_HandSolder; LCSC Part # C326057
D1: GREEN; LED_0805_2012Metric_Pad1.15x1.40mm_HandSolder; LCSC Part # C98221
R1: 10K; R_0603_1608Metric_Pad0.98x0.95mm_HandSolder; LCSC Part # C98220
R3: 330R; R_0603_1608Metric_Pad0.98x0.95mm_HandSolder; LCSC Part # C105881
SW1, SW2: SW_SPST; SW_SPST_PTS641T; LCSC Part # C285456
U1: espressif_ESP32-S3-WROOM-1-NXXX; XCVR_ESP32-S3-WROOM-1; LCSC Part # C2913204

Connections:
+3.3V: C1.2, C2.2, R1.1, U1.2 (3V3); also elsewhere on the board
/buttons/ESP32_GPIO00: SW2.1 (A), U1.27 (IO0); also elsewhere on the board
/buttons/ESP32_GPIO01: U1.39 (IO1); also elsewhere on the board
/buttons/ESP32_GPIO02: R3.1, U1.38 (IO2); also elsewhere on the board
/buttons/ESP32_GPIO03: U1.15 (IO3); also elsewhere on the board
/buttons/ESP32_GPIO04: U1.4 (IO4); also elsewhere on the board
/buttons/ESP32_GPIO05: U1.5 (IO5); also elsewhere on the board
/buttons/ESP32_GPIO06: U1.6 (IO6); also elsewhere on the board
/buttons/ESP32_GPIO07: U1.7 (IO7); also elsewhere on the board
/buttons/ESP32_GPIO08: U1.12 (IO8); also elsewhere on the board
/buttons/ESP32_GPIO09: U1.17 (IO9); also elsewhere on the board
/buttons/ESP32_GPIO14: U1.22 (IO14); also elsewhere on the board
/buttons/ESP32_GPIO17: U1.10 (IO17); also elsewhere on the board
/buttons/ESP32_GPIO18: U1.11 (IO18)
/buttons/ESP32_GPIO21: U1.23 (IO21); also elsewhere on the board
/buttons/ESP32_GPIO37: U1.30 (IO37); also elsewhere on the board
/buttons/ESP32_GPIO38: U1.31 (IO38); also elsewhere on the board
/buttons/ESP32_GPIO39: U1.32 (IO39); also elsewhere on the board
/buttons/ESP32_GPIO40: U1.33 (IO40); also elsewhere on the board
/buttons/ESP32_GPIO41: U1.34 (IO41); also elsewhere on the board
/buttons/ESP32_GPIO42: U1.35 (IO42); also elsewhere on the board
/buttons/ESP32_GPIO45: U1.26 (IO45)
/buttons/ESP32_GPIO46: U1.16 (IO46)
/buttons/ESP32_GPIO47: U1.24 (IO47); also elsewhere on the board
/buttons/ESP32_GPIO48: U1.25 (IO48); also elsewhere on the board
/display/ESP32_GPIO10_CS: U1.18 (IO10); also elsewhere on the board
/display/ESP32_GPIO11_MOSI: U1.19 (IO11); also elsewhere on the board
/display/ESP32_GPIO12_MISO: U1.20 (IO12); also elsewhere on the board
/display/ESP32_GPIO13_SCK: U1.21 (IO13); also elsewhere on the board
/mcu_block/ESP32_EN: C3.2, R1.2, SW1.1 (A), U1.3 (EN)
/mcu_block/ESP32_GPIO15_XTAL_32K_P: U1.8 (IO15)
/mcu_block/ESP32_GPIO16_XTAL_32K_N: U1.9 (IO16)
/mcu_block/ESP32_GPIO19_USB_D-: U1.13 (IO19); also elsewhere on the board
/mcu_block/ESP32_GPIO20_USB_D+: U1.14 (IO20); also elsewhere on the board
/mcu_block/ESP32_GPIO35_SDA: U1.28 (IO35); also elsewhere on the board
/mcu_block/ESP32_GPIO36_SCL: U1.29 (IO36); also elsewhere on the board
/mcu_block/ESP32_GPIO43_TX: U1.37 (IO43); also elsewhere on the board
/mcu_block/ESP32_GPIO44_RX: U1.36 (IO44); also elsewhere on the board
GND: C1.1, C2.1, C3.1, D1.1 (K), SW1.2 (B), SW2.2 (B), U1.1 (GND), U1.40 (GND), U1.41_1 (GND), U1.41_2 (GND), U1.41_3 (GND), U1.41_4 (GND), U1.41_5 (GND), U1.41_6 (GND), U1.41_7 (GND), U1.41_8 (GND), U1.41_9 (GND), U1.41_10 (GND), U1.41_11 (GND), U1.41_12 (GND), U1.41_13 (GND), U1.41_14 (GND), U1.41_15 (GND), U1.41_16 (GND), U1.41_17 (GND); also elsewhere on the board
unnamed: D1.2 (A), R3.2

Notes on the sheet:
BUZZER DRIVE SIG
dedicated to buttons
CS PIN: ACCESSORY
RESET PIN FOR DISPLAY
CS PIN: TOUCHSCREEN
SAO V2 ACCESSORY PIN 2
DC PIN FOR DISPLAY
CS PIN: FULL SD CARD
Programming Buttons
LoRa MODULE IRQ
CS PIN: DISPLAY
IRQ PIN FOR TOUCHSCREEN
CS PIN: LoRa MODULE
DEBUG LED
LoRa MODULE RESET
CS PIN: STORAGE
Picked to be software compatible with present nuggets as there are no dedicated hardware i2c pins
on-board neopixel
SAO V2 ACCESSORY PIN 1
off-board neopixel / programming

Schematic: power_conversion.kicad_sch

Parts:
C13, C14, C15, C18, C19: 10uF; C_0603_1608Metric_Pad1.08x0.95mm_HandSolder; LCSC Part # C326057
C16: 4.7uF; C_0603_1608Metric_Pad1.08x0.95mm_HandSolder; LCSC Part # C326580
C17: 0.1uF; C_0603_1608Metric_Pad1.08x0.95mm_HandSolder; LCSC Part # C92490
D10: D; D_SMA; LCSC Part # C50645
L1: 1uH; koher_MDA4020_series_inductor; LCSC Part # C2847468
L2: 2.2uH; koher_MDA4020_series_inductor; LCSC Part # C2847469
Q4: Q_NMOS_GSD; LCSC_SOT-23; LCSC Part # C91714
R27: 750K; R_0603_1608Metric_Pad0.98x0.95mm_HandSolder; LCSC Part # C137684
R28, R31: 100K; R_0603_1608Metric_Pad0.98x0.95mm_HandSolder; LCSC Part # C14675
R30: 453K; R_0603_1608Metric_Pad0.98x0.95mm_HandSolder; LCSC Part # C227908
R32: 330R; R_0603_1608Metric_Pad0.98x0.95mm_HandSolder; LCSC Part # C105881
R33, R34: 10K; R_0603_1608Metric_Pad0.98x0.95mm_HandSolder; LCSC Part # C98220
U4: TPS61023DRLR; TI_CONVERTER_SOT563; LCSC Part # C919459
U5: TLV62569DBV; LCSC_SOT-23-5; LCSC Part # C141836

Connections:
+3.3V: C18.1, C19.1, L2.2, R30.1; also elsewhere on the board
+5V: C14.1, C15.1, C16.1, C17.1, D10.1 (K), R27.1, U4.6 (VOUT), U5.1 (EN), U5.4 (VIN); also elsewhere on the board
/buttons/+BATT: C13.1, L1.1, R34.1, U4.3 (VIN); also elsewhere on the board
/buttons/+USB_IN: D10.2 (A), R32.1; also elsewhere on the board
/power_conversion/stepup_conv_en: Q4.3 (D), R34.2, U4.2 (EN)
GND: C13.2, C14.2, C15.2, C16.2, C17.2, C18.2, C19.2, Q4.2 (S), R28.2, R31.2, R33.1, U4.4 (GND), U5.2 (GND); also elsewhere on the board
unnamed: Q4.1 (G), R32.2, R33.2
unnamed: R27.2, R28.1, U4.1 (FB)
unnamed: L1.2, U4.5 (SW)
unnamed: R30.2, R31.1, U5.5 (FB)
unnamed: L2.1, U5.3 (SW)

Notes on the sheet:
step-down
step-up
diode
"R2"
+5v
0.6 * [1 + (453k/100k)] = 3.318V
Vref = 0.6V [(5/0.6) - 1]*100k = 733kohm
STEP-UP CONVERTER
STEP-DOWN CONVERTER
"R1"
R1/R2 need to be 0.1% resistors to ensure output accuracy
Set to 5.1V to ensure biasing of diode with usb power
-----General concept for power layout----- Diode prevents fighting between usb and dc/dc converter step-up converter only on when usb power is disconnected
AAs
STEP-UP CONVERTER ENABLE
USB POWER
usb
+3.3v

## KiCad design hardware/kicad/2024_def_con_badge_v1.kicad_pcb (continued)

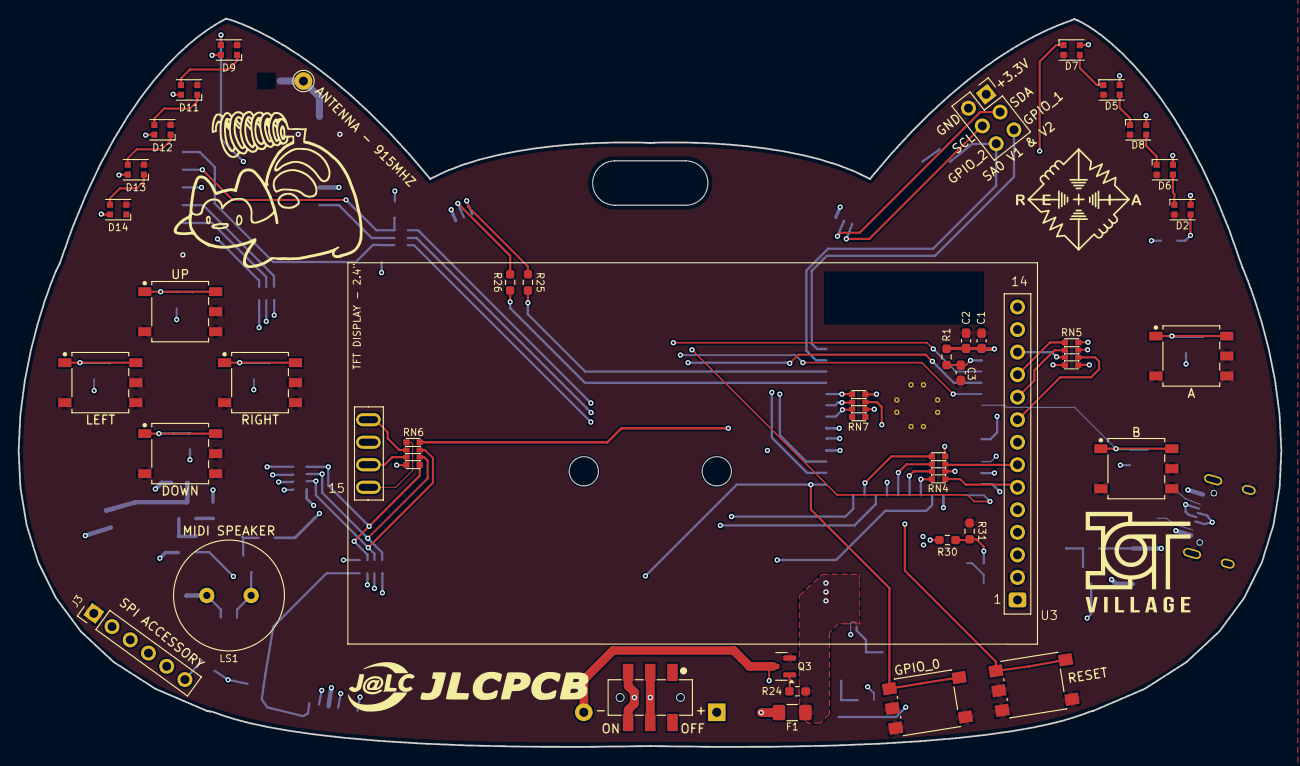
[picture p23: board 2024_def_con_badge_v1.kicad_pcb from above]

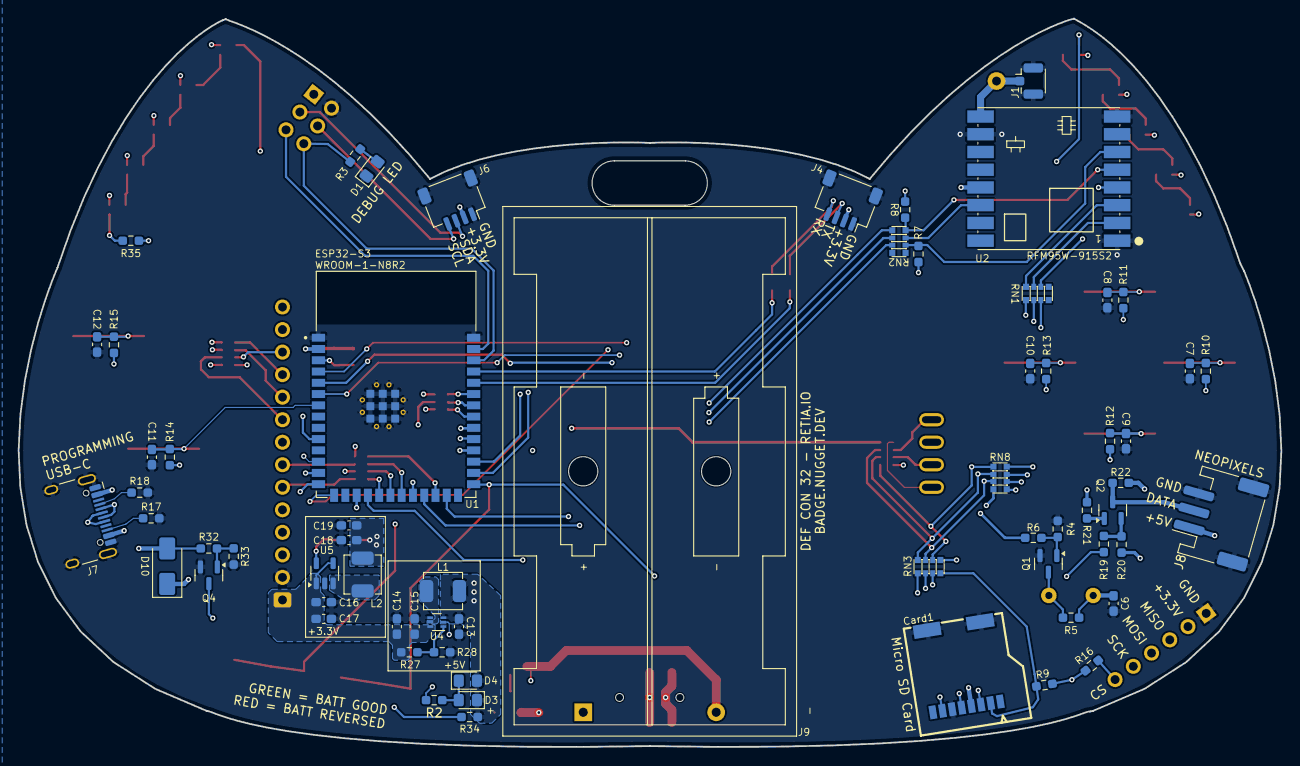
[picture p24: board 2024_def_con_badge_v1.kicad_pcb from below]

Board: 4 copper layers, 142.4 x 82.1 mm, 104 parts (65 on the bottom side), 98 nets.

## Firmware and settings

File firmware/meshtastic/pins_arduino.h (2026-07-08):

#ifndef Pins_Arduino_h
#define Pins_Arduino_h
#include "variant.h"
#include <stdint.h>
#define USB_VID 0x303a
#define USB_PID 0x1001
static const uint8_t SDA = 35;
static const uint8_t SCL = 36;
static const uint8_t SS = 48;
static const uint8_t MOSI = 11;
static const uint8_t MISO = 12;
static const uint8_t SCK = 13;
#define SPI_MOSI (11)
#define SPI_SCK (13)
#define SPI_MISO (12)
#define SPI_CS (48)
#define LED_BUILTIN (2)
#endif /* Pins_Arduino_h */

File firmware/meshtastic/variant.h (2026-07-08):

#pragma once

// --- Pin Definitions (Matching 2024 Def Con Badge v1) ---
#define PIN_LED_DEBUG 2      // green LED
#define PIN_CS_ACCESSORY -1  // not used

// --- SPI Pins (Shared by Radio and TFT Display) ---
#define PIN_SPI_SCK 13
#define PIN_SPI_MISO 12
#define PIN_SPI_MOSI 11
#define PIN_SPI_CS 48

// --- I2C ---
// Not used, but let's define defaults to avoid compilation warnings
#define PIN_I2C0_SCL 36
#define PIN_I2C0_SDA 35
#define I2C_SDA PIN_I2C0_SDA
#define I2C_SCL PIN_I2C0_SCL

// --- Heartbeat Status LED ---
#define LED_POWER PIN_LED_DEBUG
#define LED_STATE_ON 1

// --- Performance & Feature Defaults ---
#define AMBIENT_LIGHTING_AUTO_START

// --- RGB NeoPixel (Ambient Lighting) ---
#define HAS_NEOPIXEL 1
#define NEOPIXEL_COUNT 10
#define NEOPIXEL_DATA 17
#define NEOPIXEL_TYPE (NEO_GRB + NEO_KHZ800)
#define ENABLE_AMBIENT_LIGHTING

// --- Radio Setup (RFM95W) ---
#define USE_RF95
#define LORA_SCK PIN_SPI_SCK
#define LORA_MISO PIN_SPI_MISO
#define LORA_MOSI PIN_SPI_MOSI
#define LORA_CS PIN_SPI_CS
#define LORA_RESET 38
#define LORA_DIO0 21
#define LORA_DIO1 RADIOLIB_NC
#define LORA_DIO2 RADIOLIB_NC

// --- Buzzer ---
#define PIN_BUZZER 9
#define USE_PIN_BUZZER

// --- Navigation Buttons (using Trackball Input Broker) ---
#define HAS_TRACKBALL 1
#define TB_LEFT 3       // SW3
#define TB_UP 4         // SW4
#define TB_DOWN 5       // SW5
#define TB_RIGHT 6      // SW6
#define TB_PRESS 8      // SW8 (Button A)
#define TB_DIRECTION FALLING

#define BUTTON_PIN 8    // Map main user button to SW8 (Button A)
#define BUTTON_NEED_PULLUP

// --- ILI9341 TFT Display Config ---
#define ILI9341_DRIVER
#define USE_TFTDISPLAY 1
#define TFT_WIDTH 240
#define TFT_HEIGHT 320
#define SCREEN_ROTATE
#define TFT_OFFSET_X 0
#define TFT_OFFSET_Y 0
#define TFT_BUSY -1
#define ILI9341_SPI_HOST SPI2_HOST
#define TFT_SCLK PIN_SPI_SCK
#define TFT_MOSI PIN_SPI_MOSI
#define TFT_MISO PIN_SPI_MISO
#define TFT_CS 47       // CS_TFT_SCREEN
#define TFT_DC 40       // DC_TFT_SCREEN
#define TFT_RST 41      // RESET_TFT_SCREEN
#define TFT_BL -1       // Backlight hardwired to 3.3V
#define SPI_FREQUENCY 40000000
#define SPI_READ_FREQUENCY 16000000

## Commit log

2026-07-08 DEF CON badge (2024): docs, firmware releases, examples, hardware sources
    - docs: full GPIO pinout with quirks, hardware guide, flashing +
    recovery guide, SD card guide
    - firmware/doom: audio + silent merged factory images (PrBoom 2.5.0,
    shareware DOOM, badge controls, piezo SFX)
    - firmware/meshtastic: 2.7.23 standard + low-power builds, variant files
    - examples: hello-badge (buttons/LED/buzzer), sd-test (verified on
    16GB SDHC hardware)
    - hardware: KiCad 8 sources + schematic PDF
    [2024_def_con_badge_v1-B_Cu.gbl, 2024_def_con_badge_v1-B_Mask.gbs, 2024_def_con_badge_v1-B_Paste.gbp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]
2026-07-08 Add badge photo (running DOOM) as README hero; sync silkscreen names into pinout
2026-07-08 Add Meshtastic MUI touch build (2.7.23.9509528, LVGL device-ui)
2026-07-09 MUI touch build: ship touchscreen-build-bleoff — boots to home screen with factory-fresh settings
2026-07-09 Add Reticulum RNode firmware for the badge
    firmware/reticulum/: RNode v1.85 factory image (BOARD_RETIA_DCBADGE,
    headless) + flash/provision/config instructions. Hardware-verified:
    bidirectional badge<->Nibble Zero Reticulum link, 3/3 delivery proofs at
    914.875 MHz SF8/125k/CR5. Toolkit and source links point at
    RetiaLLC/NibbleReticulum and RetiaLLC/RNode_Firmware@retia-stable.
2026-07-30 Add ESP32 Bus Pirate firmware + Qwiic-connector errata
    - firmware/buspirate/: badge-native Bus Pirate (buspirate-badge.factory.bin) with
    honest transmit/attack-capable labeling and authorized-use note; links to the
    RetiaLLC/ESP32-Bus-Pirate badge-v1.0 release.
    - README: add it to the firmware index.
    - docs/hardware-errata.md (ERRATA-01) + pinout.md quirk 9: the Qwiic/STEMMA-QT
    connectors (J4/J6) are pin-reversed vs. standard; wire I2C sensors to SAO (J5).
2026-07-31 Bus Pirate guide: jump-nav ToC + GPIO scope tools; corrected to bench reality
    - Table of contents with jump links.
    - New: GPIO pin tools (on-screen logic/analogic scope, dio measure/read),
    Wi-Fi extras (lookup/ap/webui), honest 'needs an add-on module' list.
    - Corrected against hardware: mode-entry config prompts, usable vs protected
    GPIOs (1/2/18/35/36/37/43/44), system opens a shell, lookup needs connect,
    ap needs ssid+password. All new steps re-tested on the bench.
2026-07-31 Guide: add I2C Qwiic wiring photo + correct wiring guidance
    Shows the operator's real setup — a BME280 hand-wired into the badge's Qwiic
    connector — with the pin-reversal caveat (standard Qwiic cables are backwards).
2026-07-31 Guide: correct web-CLI section — it's a Wi-Fi boot mode (button), not ap+webui
2026-07-31 Bus Pirate badge-v1.2: boot-menu fix + guide (badge map, J6/SAO wiring)
    New bin sha 4c87990b… (d-pad boot terminal picker). Guide gains a KiCad badge
    map, J6 Qwiic wiring photo + SAO-port section, GPIO scope tools, jump-nav ToC,
    and corrections from a full bench self-test.
2026-08-01 bus pirate: web CLI fixed, bump to badge-v1.2.1
    Wi-Fi web CLI terminal now works (clientFd bound from the data frame,
    final bit set, max_uri_handlers raised). Drop the known-limitation
    caveat in README/GUIDE; bump tag + factory.bin SHA to badge-v1.2.1.
